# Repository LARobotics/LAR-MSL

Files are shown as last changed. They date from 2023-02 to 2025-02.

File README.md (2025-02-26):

LAR
# LAR@MSL

## Links
 - [Website] <https://lar.dei.uminho.pt/>
 - [Youtube] <https://www.youtube.com/@lar_uminho>
 - [Instagram] <https://www.instagram.com/lar_uminho>
 - [TikTok] <https://www.tiktok.com/@lar_uminho>
 - [Facebook] <https://www.facebook.com/profile.php?id=100088692420376>

## Our robot: 
Robot

# Base Station and Strategy:
The Base Station and Strategy was developed in Python 3.11 and is one of the most important tools for the robots to be able to play. It handles the communications between the Base Station and the robots and even from the RefBox using WebSockets. The Strategy works with the inputs from the robots, calculates the group of skills for that game state, and gives that information back to the robots.

# Calibration Tools:
This folder contains Calibration tools to simplify the calibration of cameras and their alignment. It was made in Python and saves a lot of time when the robot is disassembled and needs to be calibrated.

# Hardware and 3D CADS
Here are available the 3D CAD files from the robot, which is made by either aluminium or plastic PLA. There are still hardware being developed and some of them are from previous team generations, but the ones made this year are available here.

# Player
This is the main robot code that runs on the robot's main computer. It also has the ESP32 code that runs on the Robot Microcontroller.

# Tutorial
Here are some tutorials for the things that are used by the team, for example the use of YOLO, Cameras through Ethernet, Ubuntu installation etc…

# Yolo
In this folder are available Datasets and Code that are used by the Team. It is also being made a version of running the Yolo network in Golang, the language used in the Robot.

### Contacts
 - <fernando@dei.uminho.pt>
 - <gil@dei.uminho.pt>

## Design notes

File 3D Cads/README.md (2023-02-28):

LAR
# Hardware and 3D Cads

## Includes:
- Structure
- Dribbler
- Kick
- PCB
- Power Box
- Kinect Support
- Omni Support
- Lidar Support

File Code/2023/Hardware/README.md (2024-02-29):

# Hardware
Baudrate 115200

Timeout 200ms

##Installation

$ sudo chmod 777 /dev/ttyUSB*

$ go run . ttyUSB*

#Full packet (receive) :

String : bearing_angle,Battery,temperature_OMNI, X_displacement, Y_displacement

| Variable | Range |
| --- | --- |
| bearing_angle  | -180 -> 180  |
| Battery  | 0 -> max battery voltage  |
| temperature_OMNI  |  |
| X_displacement  | 0 -> 1000  |
| Y_displacement  | 0 -> 1000  |

#Commands

Full packet  (send)

String : linear_speed,angular_speed,direction,drib1_vel,drib2_vel, Kick_time #resetenc

| Variable | Range |
| --- | --- |
| linear_speed  | 0 -> 100  |
| angular_speed  | -100 -> 100  |
| direction  | 0 ->360  |
| drib1_vel  | 0 -> 100  |
| drib2_vel  | 0 -> 100  |
| Kick_time  | 0 -> 15 |

OMNI 3MD PID Components 

String: 'P',Kp, ki, kd 

| Variable | Range |
| --- | --- |
| Kp  | 0 -> 100  |
| Ki  | 0 -> 100  |
| Kd  | 0 ->360  |

OMNI 3MD angular speed 

String: 'W',rotational_sp 

| Variable | Range |
| --- | --- |
| angular_speed  | -100 -> 100  |

OMNI 3MD linear and rotational speed 
String: 'M',linear_speed,angular_speed,direction, 

| Variable | Range |
| --- | --- |
| linear_speed  | 0 -> 100  |
| angular_speed  | -100 -> 100  |
| direction  | 0 ->360  |

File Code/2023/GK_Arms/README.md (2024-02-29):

# GK_Arms
This repository is dedicated for the goal keeper moving parts.

For the moving parts to move, it is used a raspberry pi pico to control the motor (main.py).

The import.py is the file that sends via serial the command for the pi pico to activate the motor.

This repository contains a tutorial of how to install and use Thonny (IDE for raspberry pi pico)

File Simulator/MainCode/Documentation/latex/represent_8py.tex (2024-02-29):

\hypertarget{represent_8py}{}\doxysection{v03/represent.py File Reference}
\label{represent_8py}\index{v03/represent.py@{v03/represent.py}}
\doxysubsection*{Classes}
\begin{DoxyCompactItemize}
\item 
class \mbox{\hyperlink{classrepresent_1_1_draw}{represent.\+Draw}}
\end{DoxyCompactItemize}
\doxysubsection*{Namespaces}
\begin{DoxyCompactItemize}
\item 
namespace \mbox{\hyperlink{namespacerepresent}{represent}}
\end{DoxyCompactItemize}
\doxysubsection*{Functions}
\begin{DoxyCompactItemize}
\item 
def \mbox{\hyperlink{namespacerepresent_aa5588bfe59ad341def799e75c61164e5}{represent.\+pol2cart}} (rho, phi)
\end{DoxyCompactItemize}
\doxysubsection*{Variables}
\begin{DoxyCompactItemize}
\item 
tuple \mbox{\hyperlink{namespacerepresent_a306ae13e5d31331a7cd58b41778ff506}{represent.\+server\+Address\+Port}} = (\char`\"{}localhost\char`\"{}, 20000)
\item 
\mbox{\hyperlink{namespacerepresent_a5a9aeb93b6b3772014caec14be52f55a}{represent.\+UDPClient\+Socket}} = socket.\+socket(family=socket.\+AF\+\_\+\+INET, type=socket.\+SOCK\+\_\+\+DGRAM)
\item 
list \mbox{\hyperlink{namespacerepresent_a486d0cff411ffd8d014e9d40a42c79ba}{represent.\+Ball}} = \mbox{[}0, 0\mbox{]}
\item 
list \mbox{\hyperlink{namespacerepresent_a32969535d1ac8ca3c024cc3d4650f2a2}{represent.\+Robots}} = \mbox{[}\mbox{[}0, 0, 0\mbox{]}, \mbox{[}0, 0, 0\mbox{]}, \mbox{[}0, 0, 0\mbox{]}, \mbox{[}0, 0, 0\mbox{]}, \mbox{[}0, 0, 0\mbox{]}\mbox{]}
\item 
\mbox{\hyperlink{namespacerepresent_aa6ba4148b26b317da122f96b56750bab}{represent.\+App}} = Draw(3)
\item 
\mbox{\hyperlink{namespacerepresent_a6c4a21d543502a43690d8051032f9db6}{represent.\+message}} = UDPClient\+Socket.\+recvfrom(1024)
\item 
\mbox{\hyperlink{namespacerepresent_ad7f4d1bb368262bdb7cb67b091ef459e}{represent.\+To\+Draw}} = eval(message\mbox{[}0\mbox{]}.decode())
\item 
\mbox{\hyperlink{namespacerepresent_a0a21a2b54add9912bfbd176ac16a054a}{represent.\+tempo}} = time.\+time()
\end{DoxyCompactItemize}

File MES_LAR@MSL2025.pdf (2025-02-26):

# LAR@MSL – M.E.S. 2025

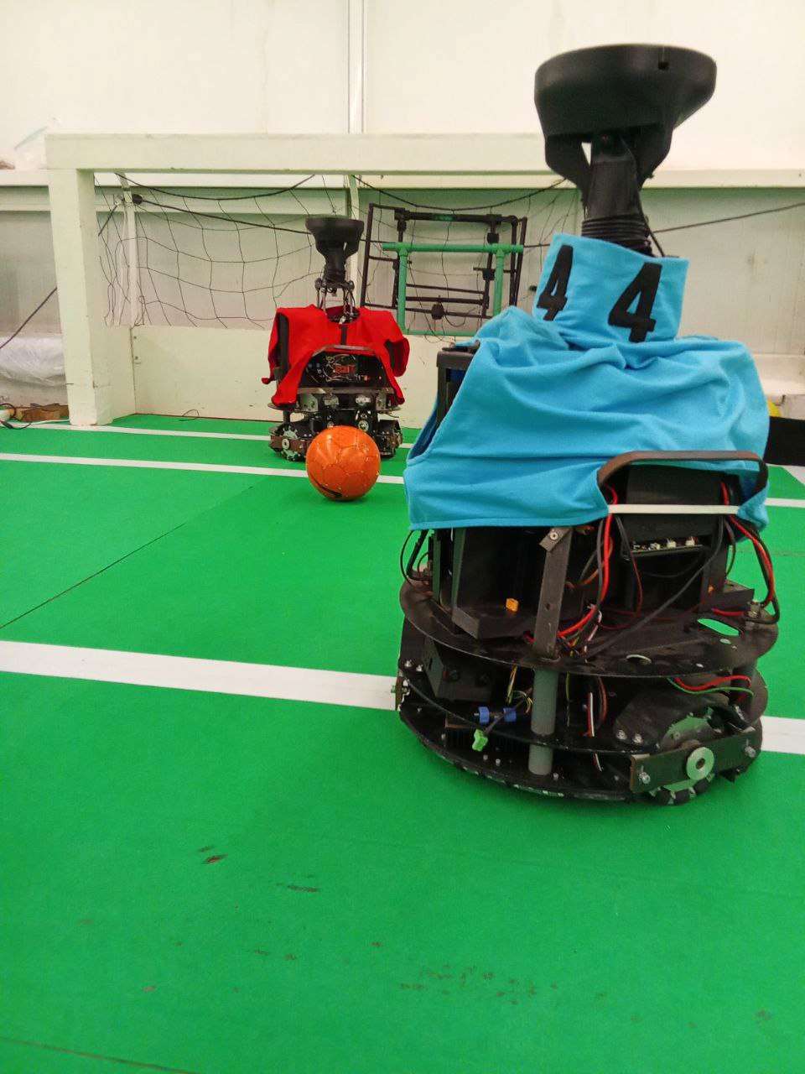
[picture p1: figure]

## Robot Overview

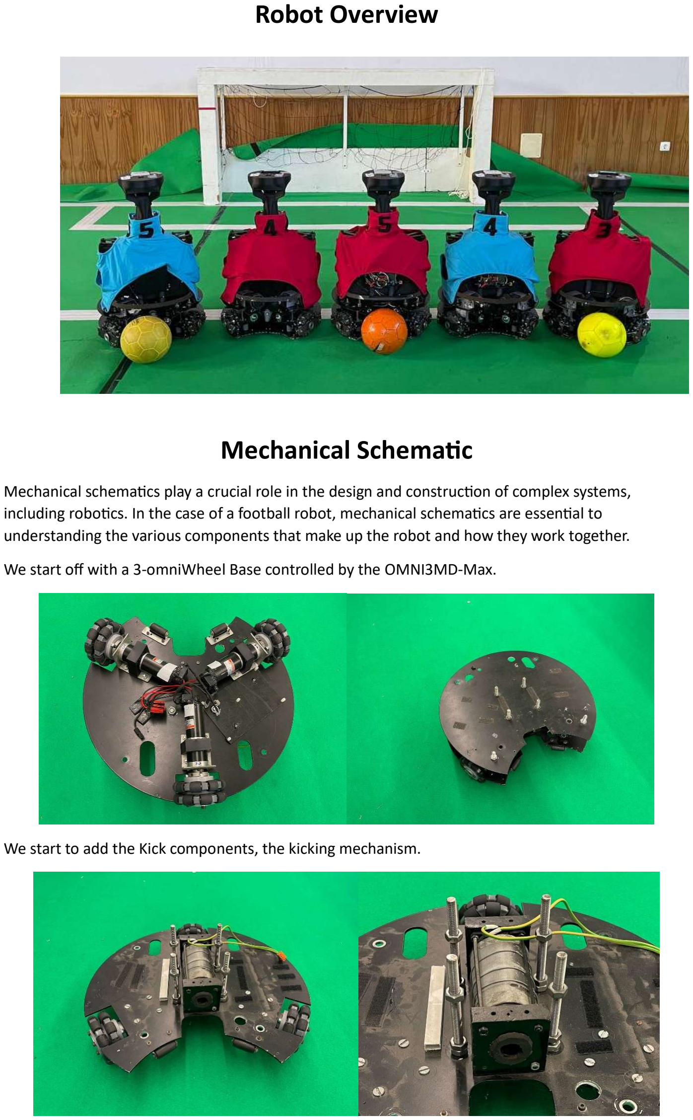
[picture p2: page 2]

## Mechanical Schemac

Mechanical schemacs play a crucial role in the design and construcon of complex systems, including robocs. In the case of a football robot, mechanical schemacs are essenal to understanding the various components that make up the robot and how they work together. We start off with a 3-omniWheel Base controlled by the OMNI3MD-Max.

We start to add the Kick components, the kicking mechanism.

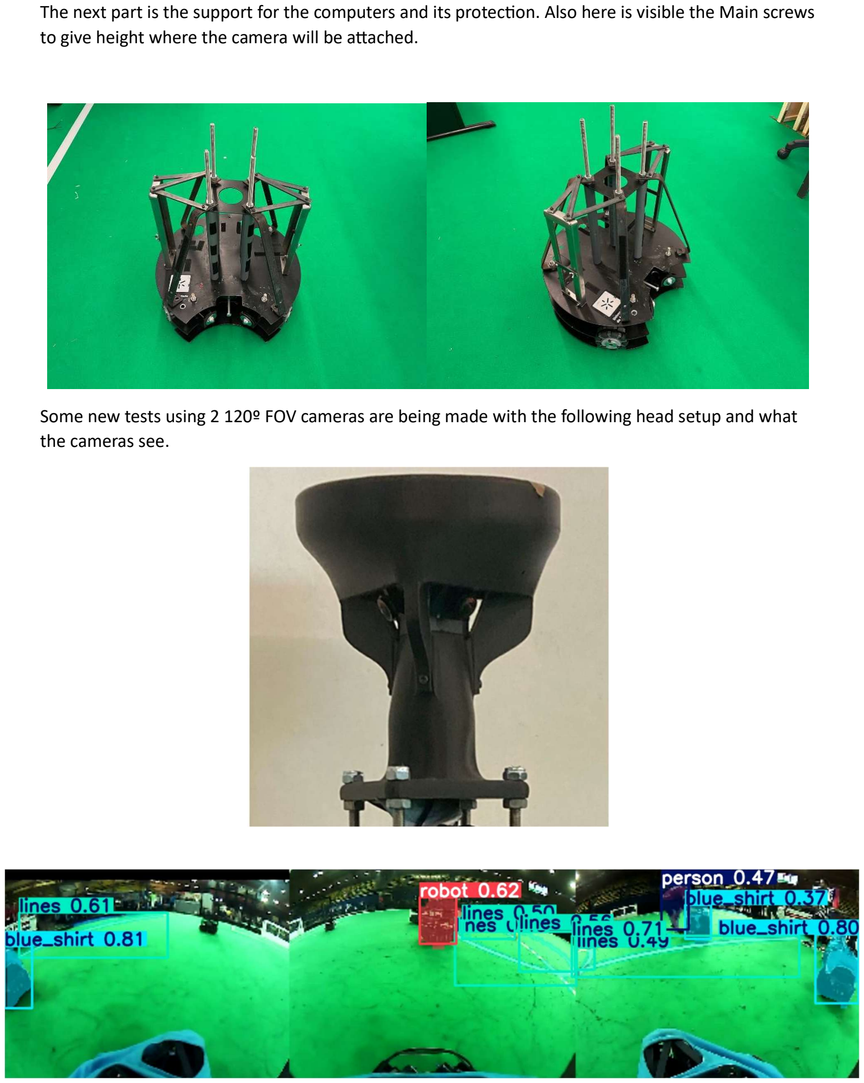
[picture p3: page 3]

The next part is the support for the computers and its protecon. Also here is visible the Main screws to give height where the camera will be aached.

Some new tests using 2 120º FOV cameras are being made with the following head setup and what the cameras see.

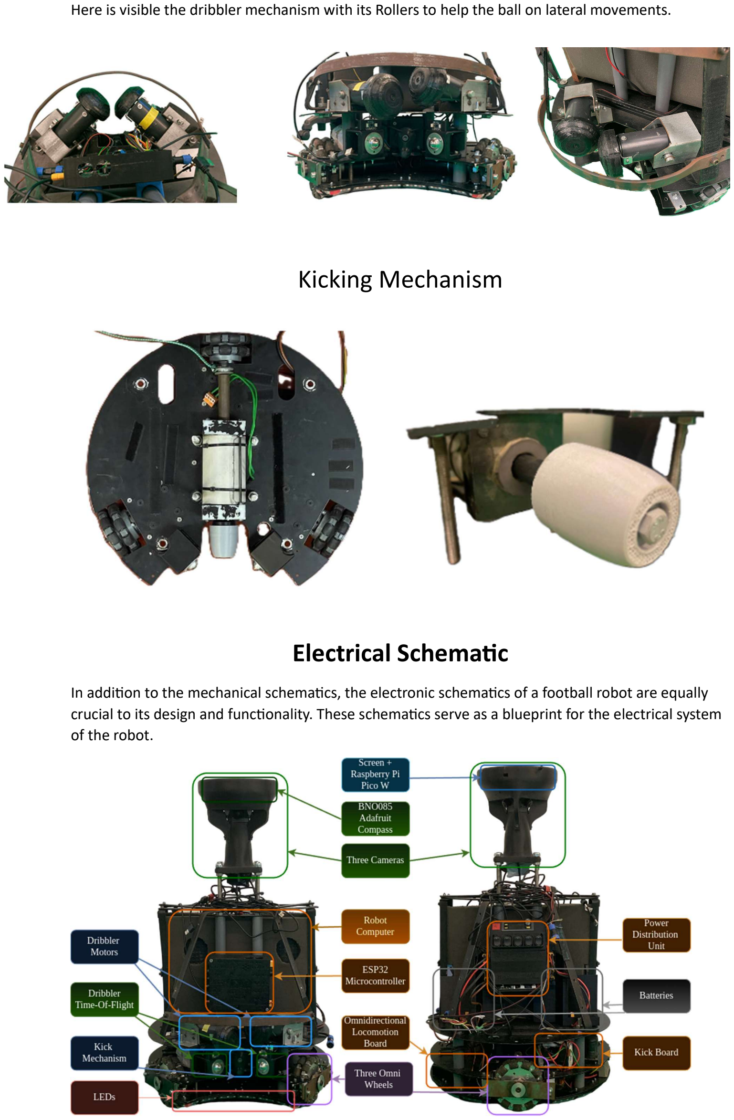
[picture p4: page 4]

Here is visible the dribbler mechanism with its Rollers to help the ball on lateral movements.

## Kicking Mechanism

## Electrical Schemac

In addion to the mechanical schemacs, the electronic schemacs of a football robot are equally crucial to its design and funconality. These schemacs serve as a blueprint for the electrical system of the robot.

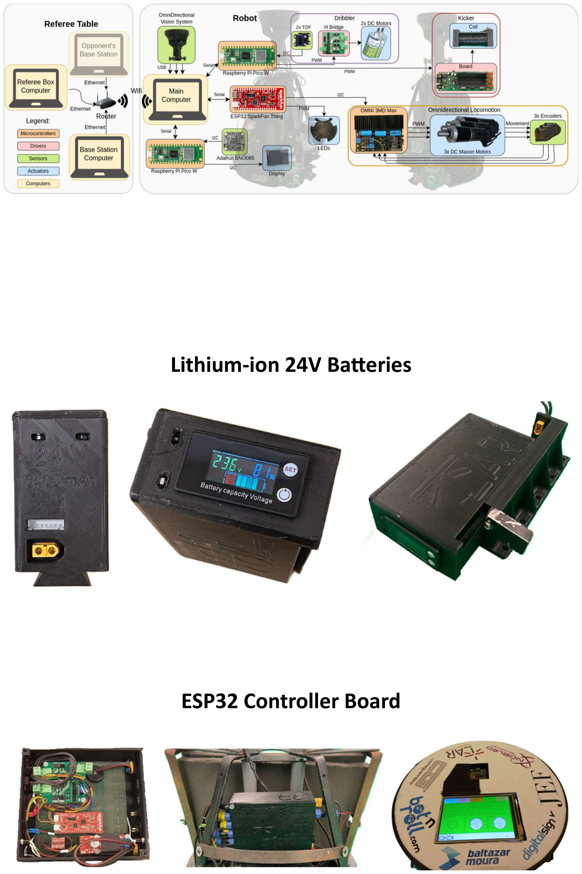
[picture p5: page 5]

## Lithium-ion 24V Baeries

## ESP32 Controller Board

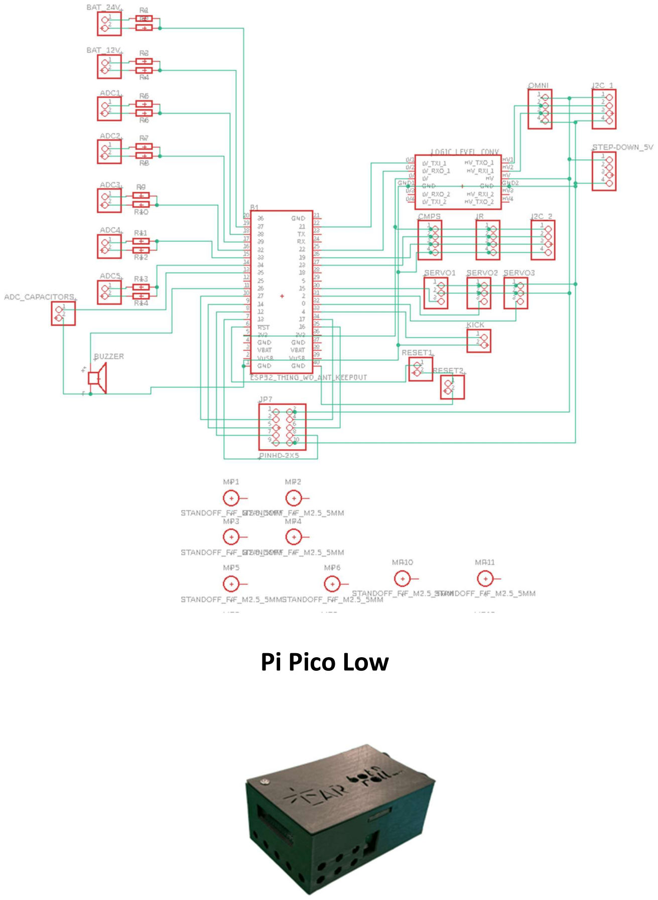
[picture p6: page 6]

## Pi Pico Low

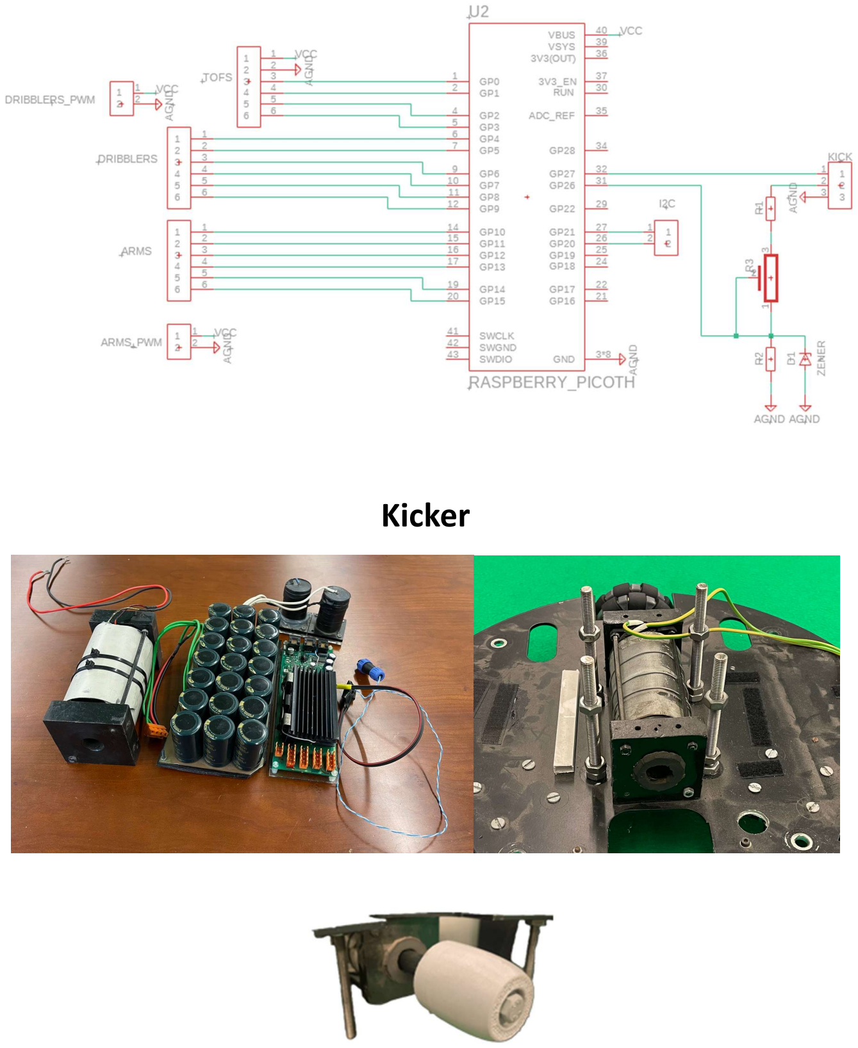
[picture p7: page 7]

## Kicker

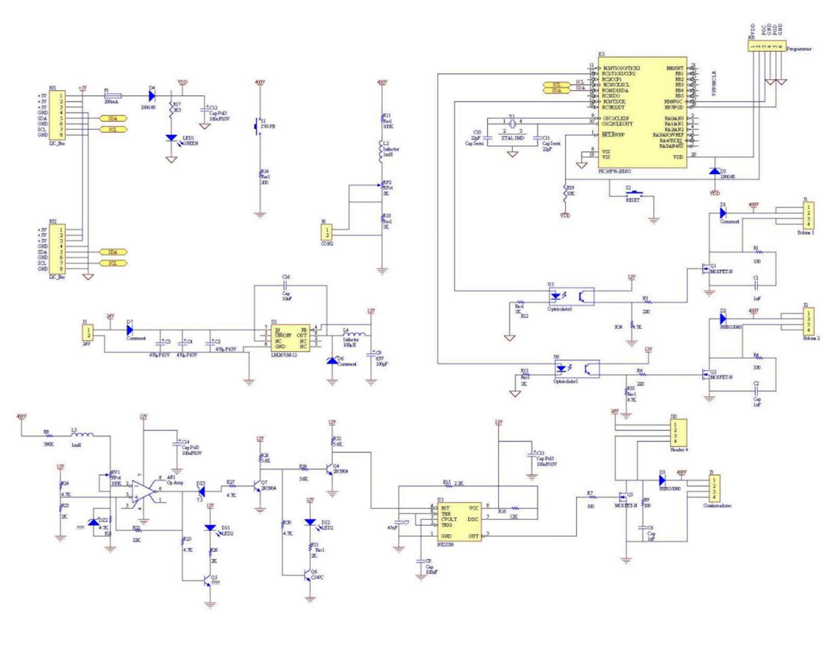
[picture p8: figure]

## Power Box

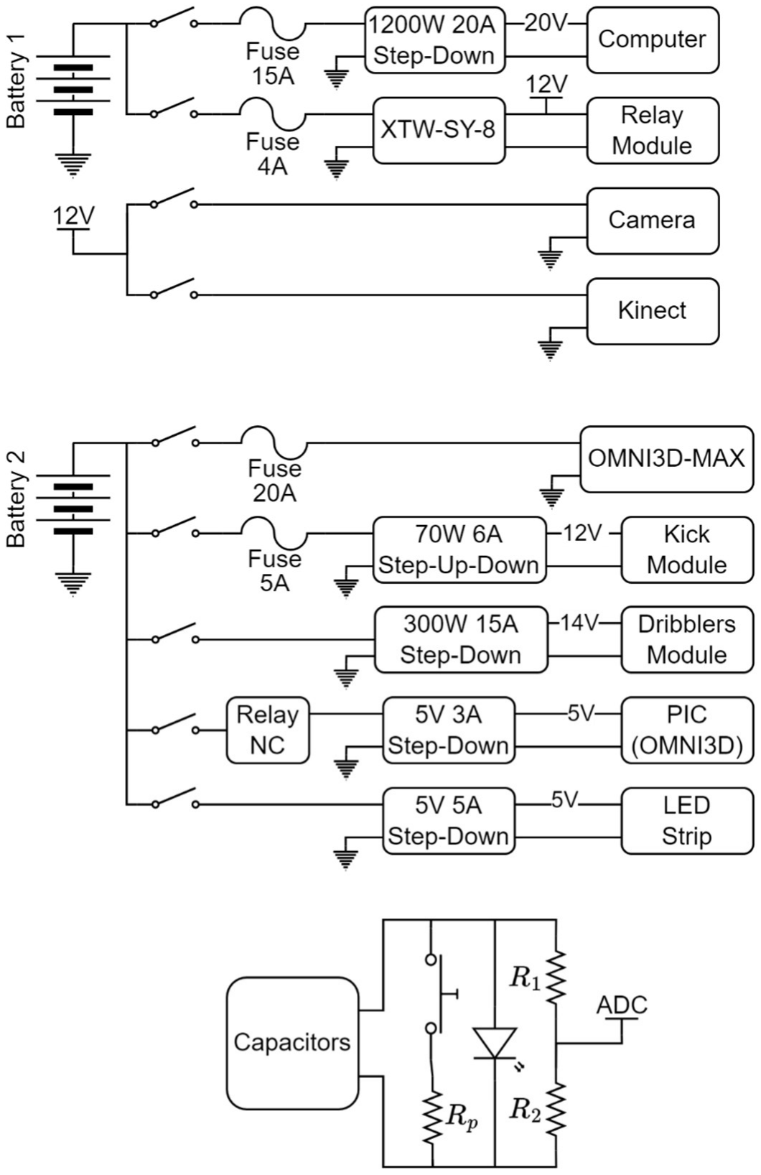
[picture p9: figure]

## Soware Schemac

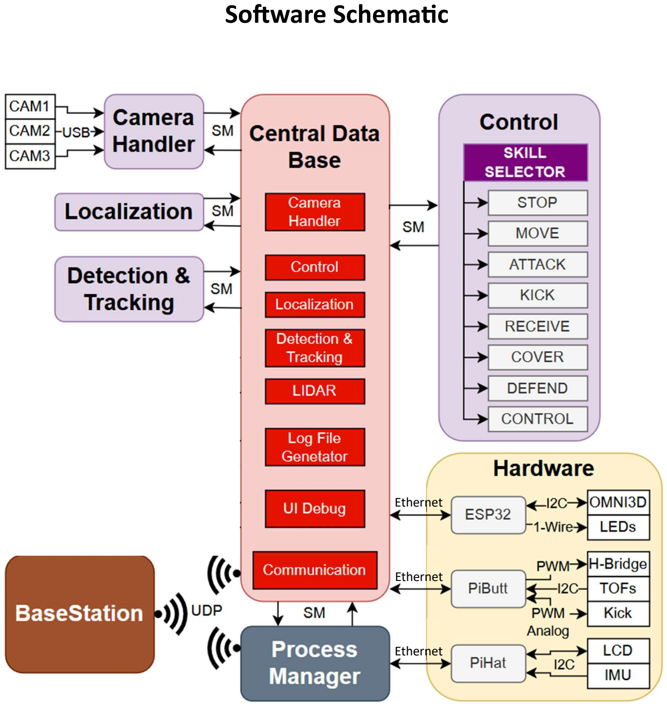
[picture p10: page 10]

Ethernet

Ethernet

Ethernet

## Base Staon UI

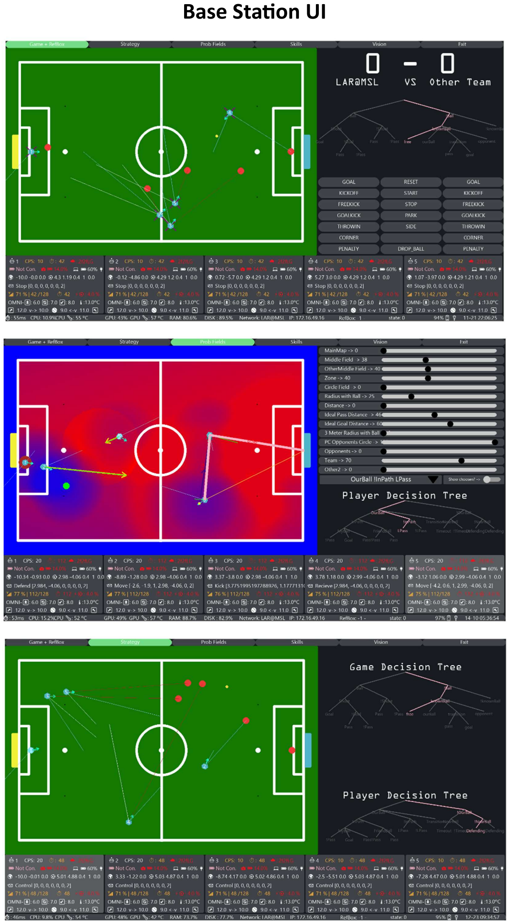
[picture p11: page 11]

## Simulator Architecture

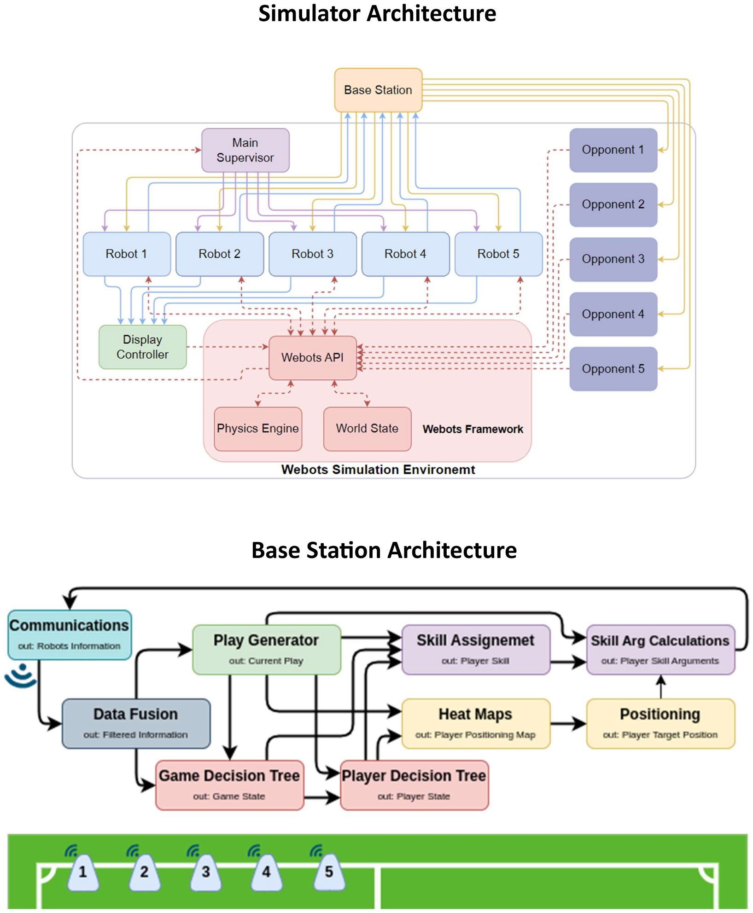
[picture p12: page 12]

## Base Staon Architecture

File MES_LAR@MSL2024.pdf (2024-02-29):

# LAR@MSL – M.E.S. 2024

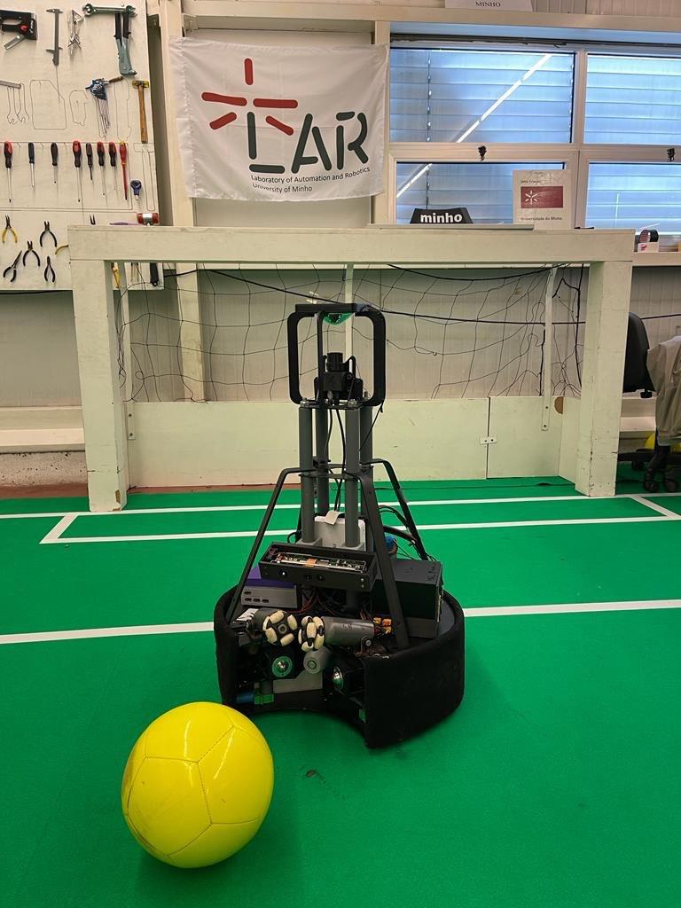
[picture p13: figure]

## Robot Overview

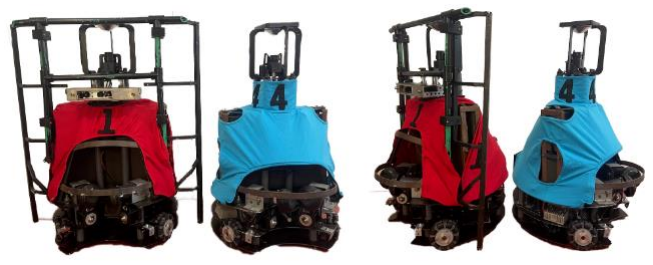
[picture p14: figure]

## Mechanical Schematic

Mechanical schematics play a crucial role in the design and construction of complex systems, including robotics. In the case of a football robot, mechanical schematics are essential to understanding the various components that make up the robot and how they work together.

We start off with a 3-omniWheel Base controlled by the OMNI3MD-Max.

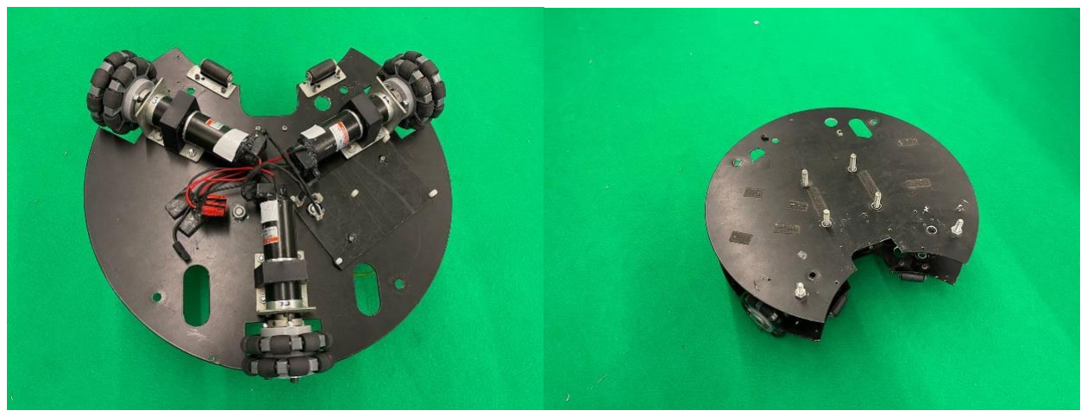
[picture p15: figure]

We start to add the Kick components, the kicking mechanism.

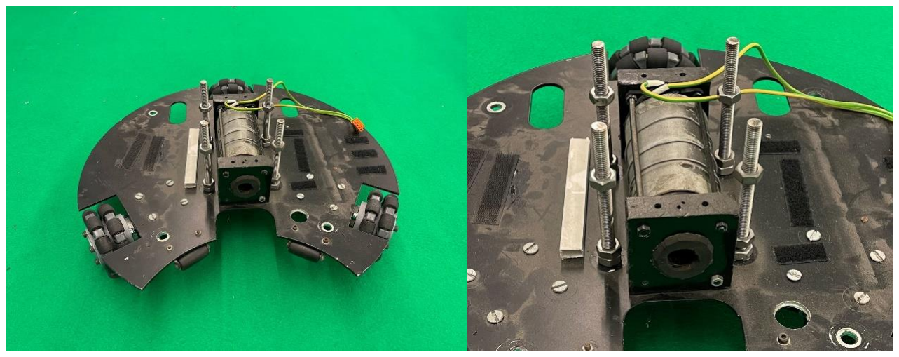
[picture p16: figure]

The next part is the support for the computers and its protection. Also here is visible the Main screws to give height where the camera will be attached.

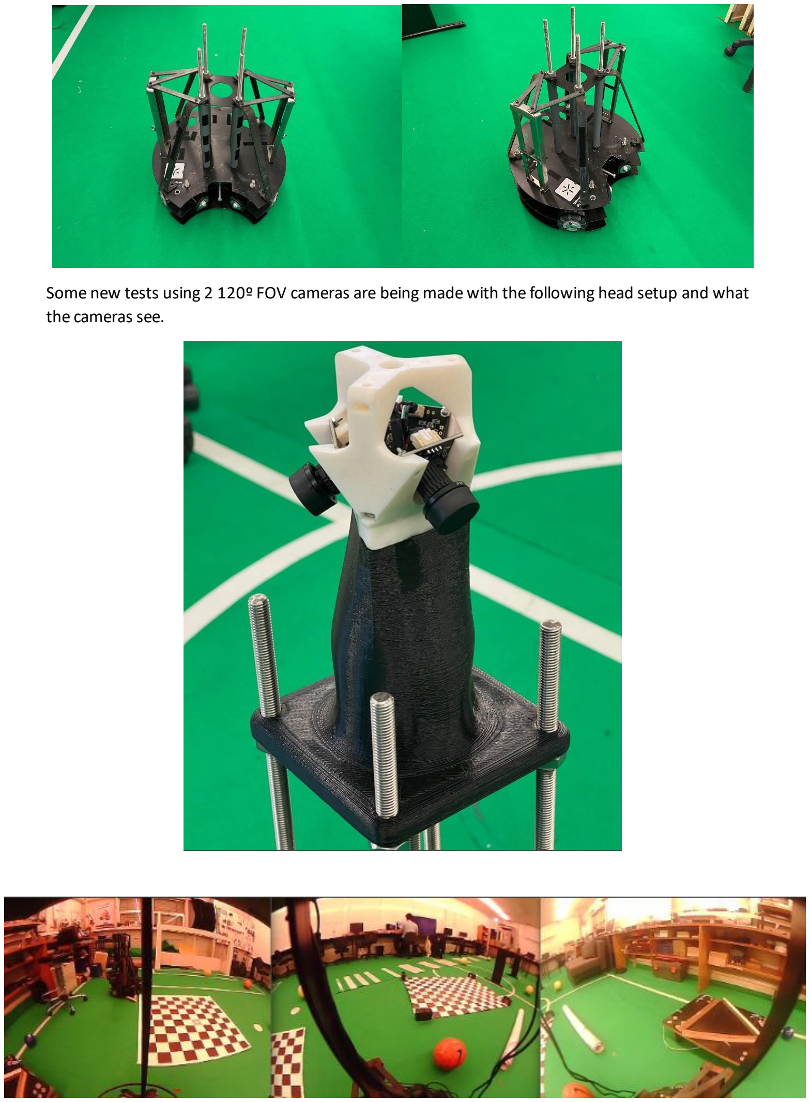
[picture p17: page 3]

Some new tests using 2 120º FOV cameras are being made with the following head setup and what the cameras see.

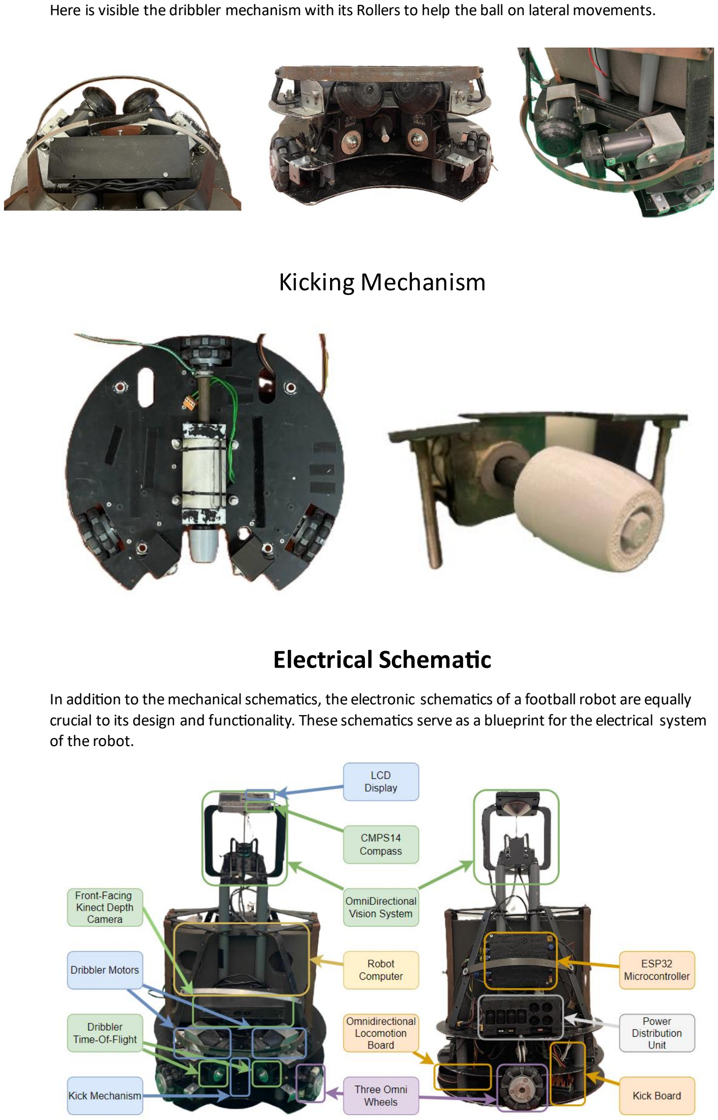
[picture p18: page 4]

Here is visible the dribbler mechanism with its Rollers to help the ball on lateral movements.

## Kicking Mechanism

## Electrical Schematic

In addition to the mechanical schematics, the electronic schematics of a football robot are equally crucial to its design and functionality. These schematics serve as a blueprint for the electrical system of the robot.

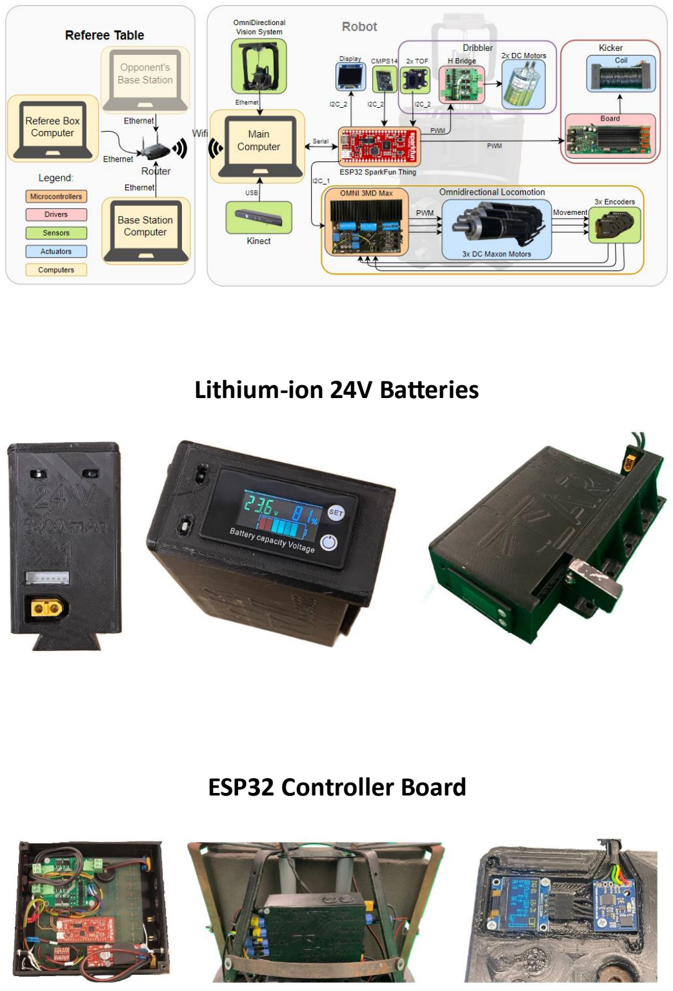
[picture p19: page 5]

## Lithium-ion 24V Batteries

## ESP32 Controller Board

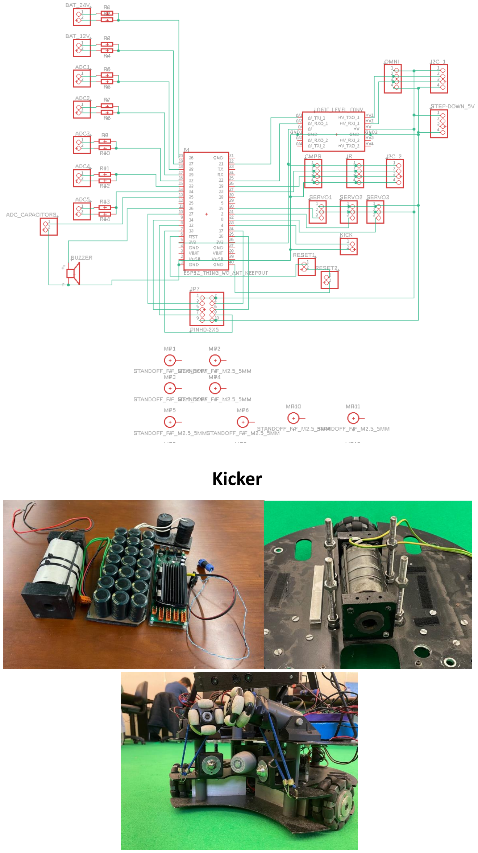
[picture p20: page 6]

## Kicker

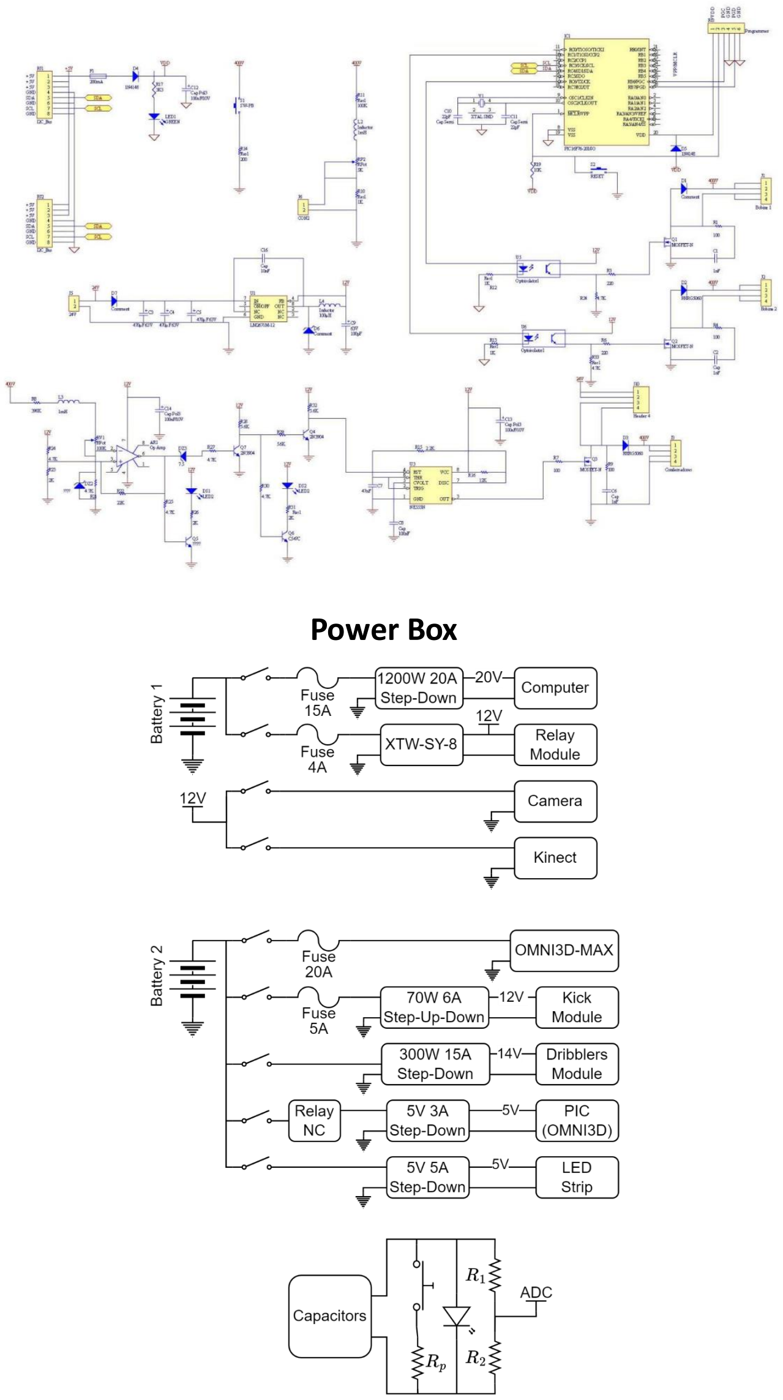
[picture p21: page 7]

## Power Box

## Software Schematic

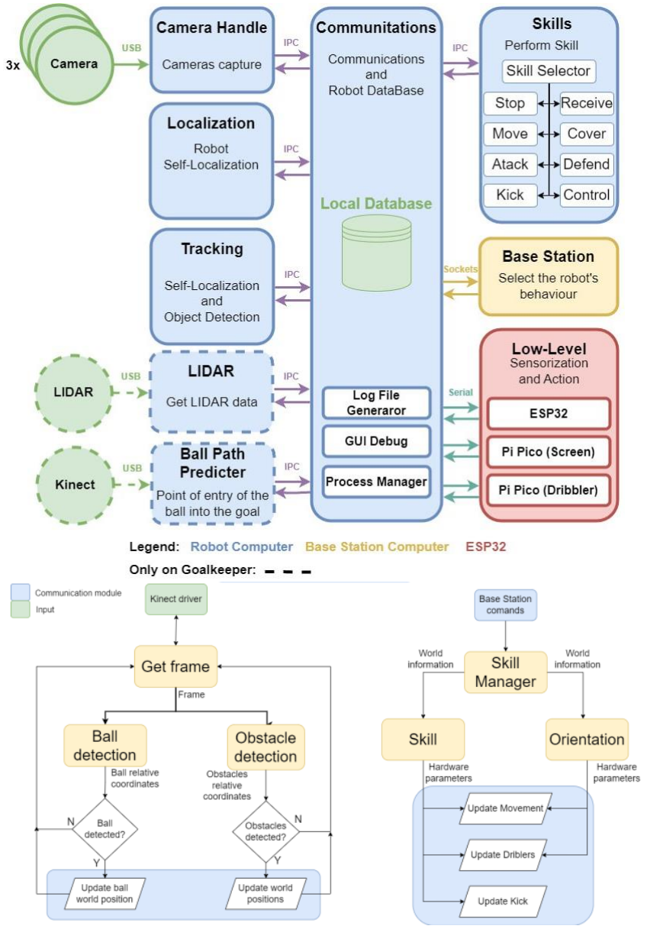
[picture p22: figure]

## Base Station UI

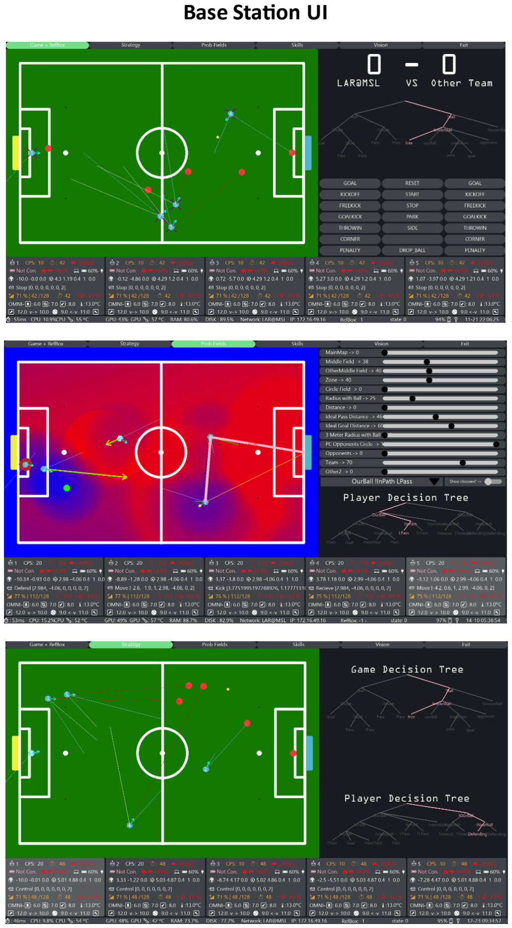
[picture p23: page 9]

## Simulator Architecture

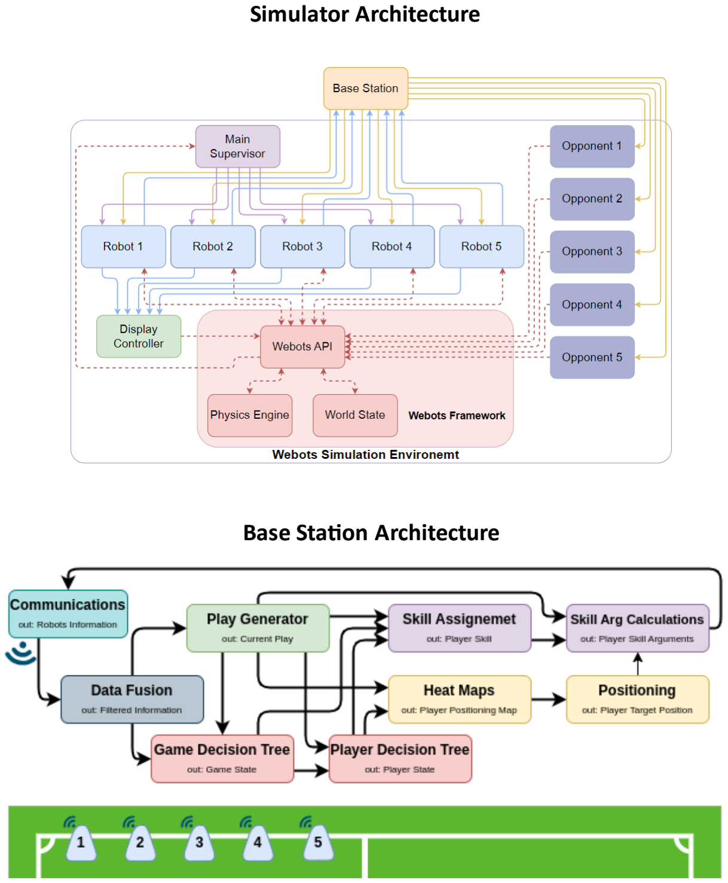
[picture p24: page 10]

## Base Station Architecture

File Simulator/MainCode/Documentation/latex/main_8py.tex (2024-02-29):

\hypertarget{main_8py}{}\doxysection{v03/main.py File Reference}
\label{main_8py}\index{v03/main.py@{v03/main.py}}
\doxysubsection*{Namespaces}
\begin{DoxyCompactItemize}
\item 
namespace \mbox{\hyperlink{namespacemain}{main}}
\end{DoxyCompactItemize}
\doxysubsection*{Variables}
\begin{DoxyCompactItemize}
\item 
\mbox{\hyperlink{namespacemain_a2c732fd126c78a0f5d3bbc0ba2087bfc}{main.\+Strategy\+DT}} = json.\+load(f)
\item 
int \mbox{\hyperlink{namespacemain_a760b0c315261c045a6205f78237a3ac3}{main.\+DRAW}} = 0
\item 
\mbox{\hyperlink{namespacemain_a4a80d210025e65a48c2237a3ff27bcb3}{main.\+App}} = Draw(3)
\item 
tuple \mbox{\hyperlink{namespacemain_a59063a6237aa4927da56261ae75edbe5}{main.\+server\+Address\+Port}} = (\char`\"{}localhost\char`\"{}, 19998)
\item 
\mbox{\hyperlink{namespacemain_a476fcb878fb3965b1c55fa5c442c6c20}{main.\+Processing\+Socket}} = socket.\+socket(family=socket.\+AF\+\_\+\+INET, type=socket.\+SOCK\+\_\+\+DGRAM)
\item 
list \mbox{\hyperlink{namespacemain_a289e4044e5b783704fccca758f093d85}{main.\+IPS}} = \mbox{[}\char`\"{}localhost\char`\"{}, \char`\"{}localhost\char`\"{}, \char`\"{}localhost\char`\"{}, \char`\"{}localhost\char`\"{}, \char`\"{}localhost\char`\"{}, \char`\"{}localhost\char`\"{}, 2\mbox{]}
\item 
list \mbox{\hyperlink{namespacemain_a74abab1c427332984c688174a7a2fa0d}{main.\+Robots}} = \mbox{[}Robot(a+1, IPS\mbox{[}0\mbox{]}, IPS\mbox{[}a+1\mbox{]}, 0, IPS\mbox{[}-\/1\mbox{]}) for a in range(5)\mbox{]}
\item 
int \mbox{\hyperlink{namespacemain_ae35795b6540bc96398be5e8232eb3c04}{main.\+kick}} = 0
\item 
int \mbox{\hyperlink{namespacemain_ad7991273b99bb2dfcba025791cece825}{main.\+recebe}} = 0
\item 
\mbox{\hyperlink{namespacemain_a1eb846a19d2fb4a2dd52b06531da303d}{main.\+init\+Time}} = time.\+time()
\item 
\mbox{\hyperlink{namespacemain_a79977f30964906ba8f47e199d7142cc0}{main.\+loop\+Time}} = time.\+time()
\item 
\mbox{\hyperlink{namespacemain_ada24c0f5d143f130aceaf05ae35895fd}{main.\+end}}
\item 
\mbox{\hyperlink{namespacemain_a2919b89f5fa43212425c4171bc4e460f}{main.\+packet}}
\end{DoxyCompactItemize}

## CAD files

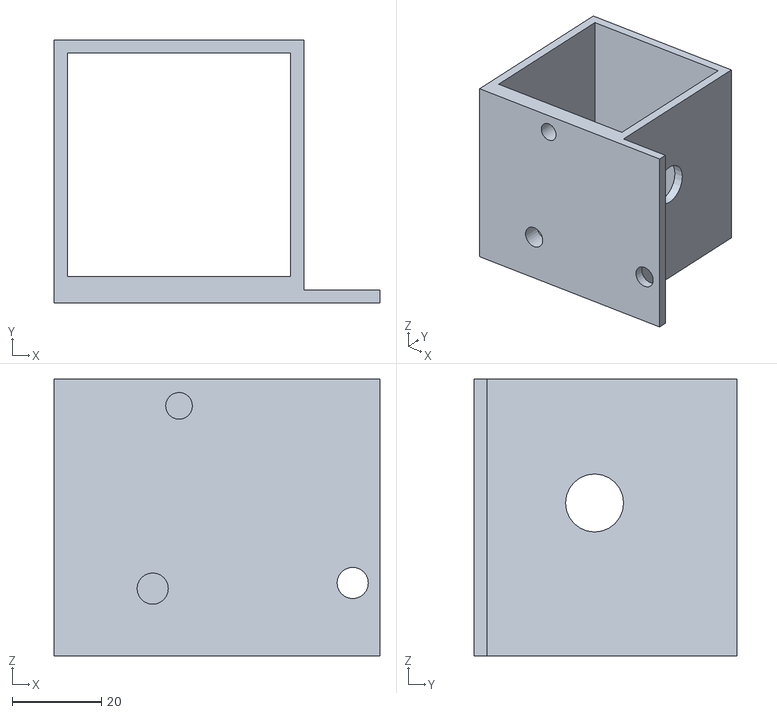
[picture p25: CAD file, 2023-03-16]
3D Cads/Dribbler/Dribbler_4E (cube).obj
73.0 x 59.0 x 62.0

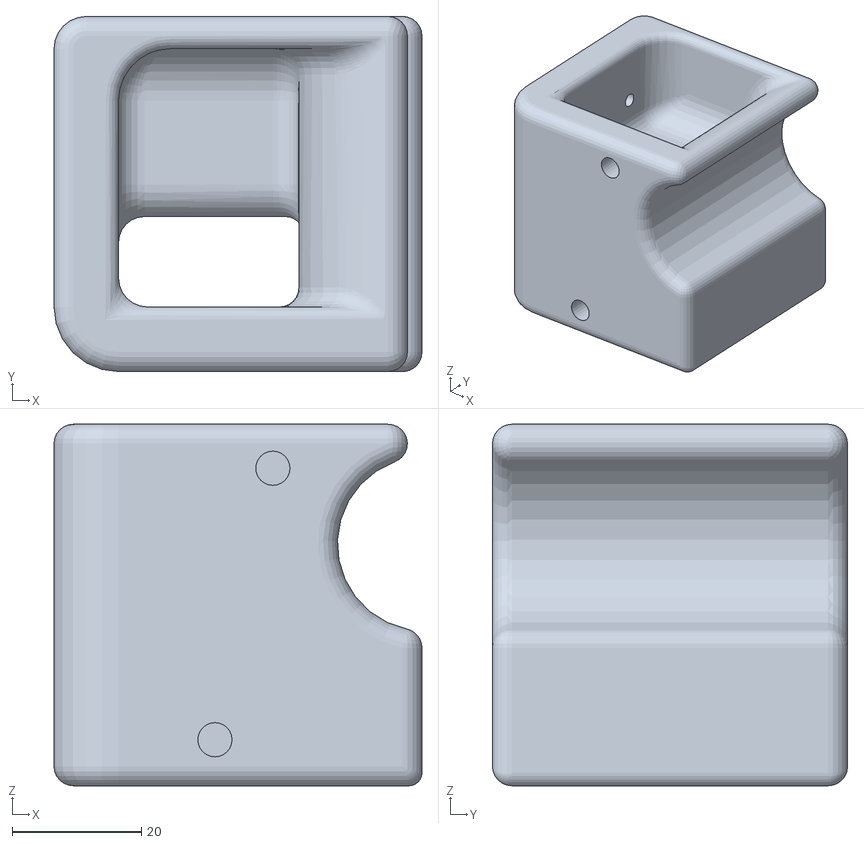
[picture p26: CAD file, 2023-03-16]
3D Cads/Dribbler/Rollers/LeftRollerCube.obj
57.0 x 55.0 x 56.0

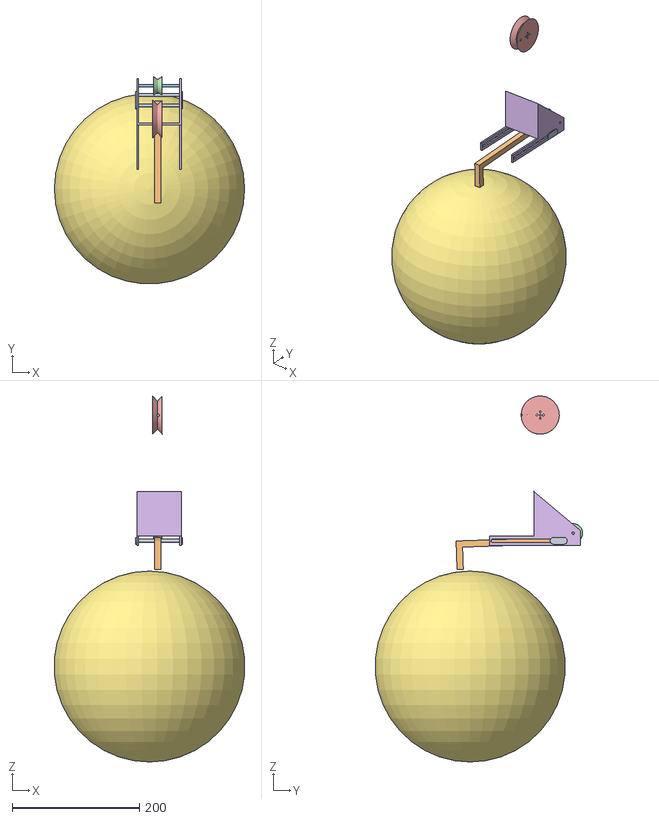
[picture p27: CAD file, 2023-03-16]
3D Cads/Kick/Kick.obj
299.0 x 325.6 x 575.0

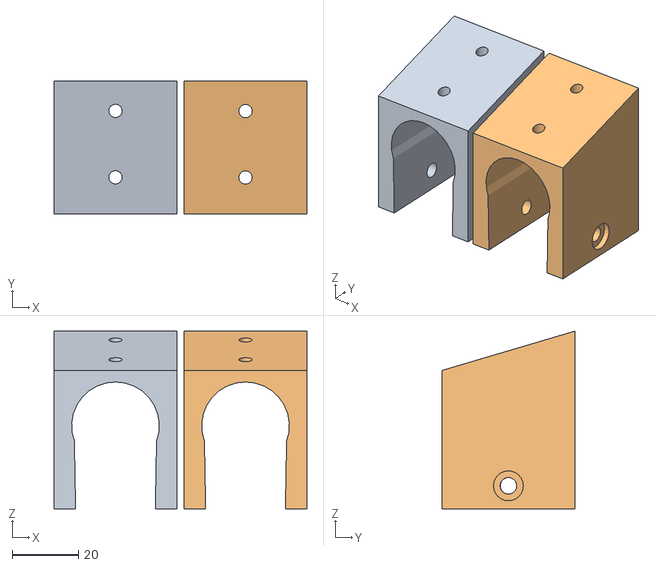
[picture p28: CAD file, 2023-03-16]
3D Cads/Kinect Support/BoxSupport.obj
76.1 x 40.1 x 53.5

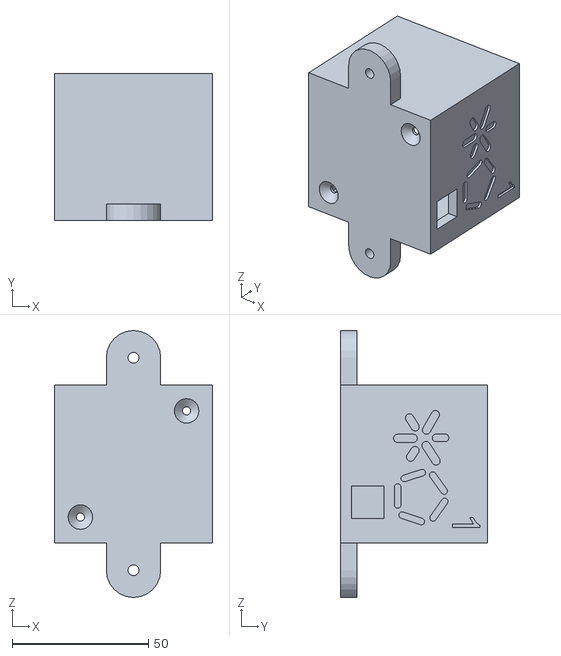
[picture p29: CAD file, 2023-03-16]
3D Cads/Lidar Support/LidarSupport.obj
58.0 x 54.0 x 98.0

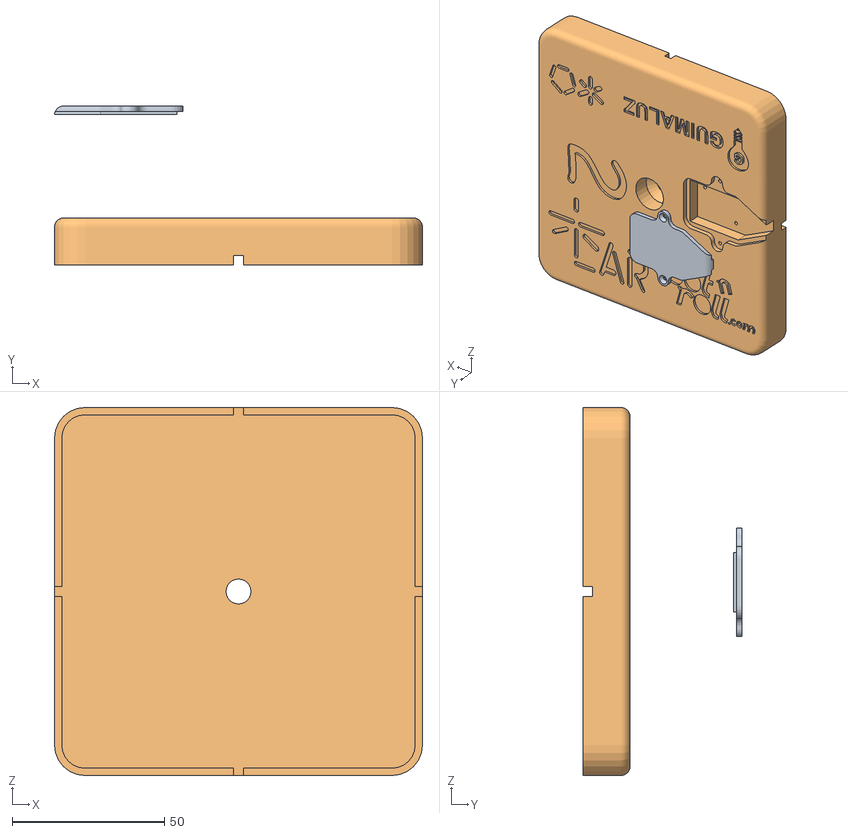
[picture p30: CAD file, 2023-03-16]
3D Cads/Omni Support/RobotCover.obj
121.0 x 52.3 x 121.0

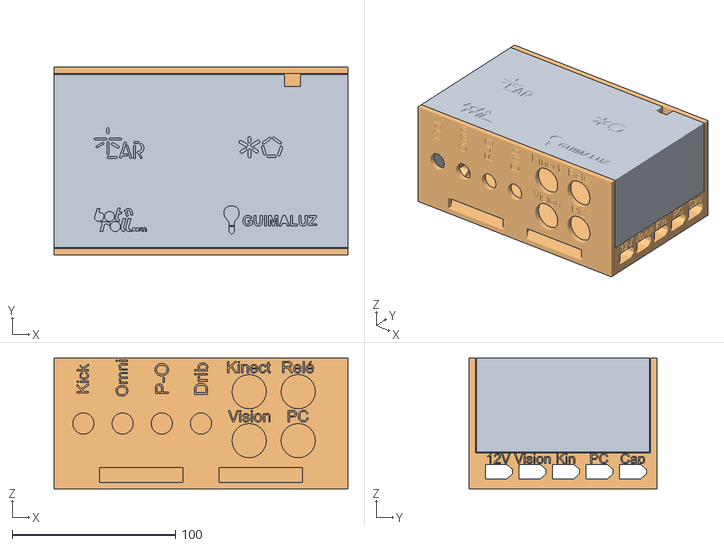
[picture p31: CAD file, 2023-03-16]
3D Cads/Power Box/PowerBox.obj
180.0 x 115.0 x 80.0

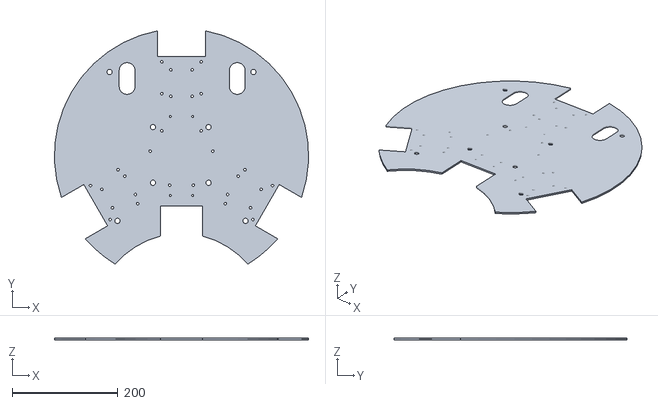
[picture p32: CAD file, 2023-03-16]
3D Cads/Structure/MiddlePlate.obj
479.4 x 440.6 x 3.00

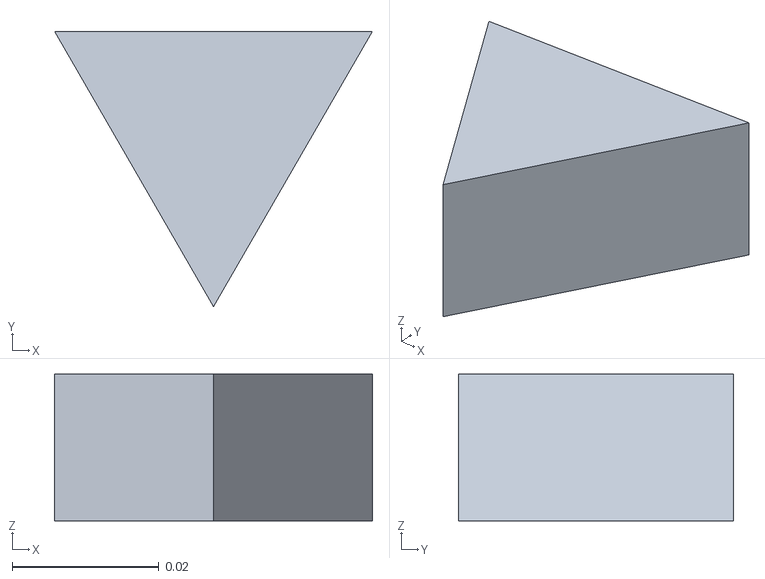
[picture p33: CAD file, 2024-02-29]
Simulator/otherSimulationFiles/MSLSuperSimplePyramide.stl
0.0433 x 0.0375 x 0.02

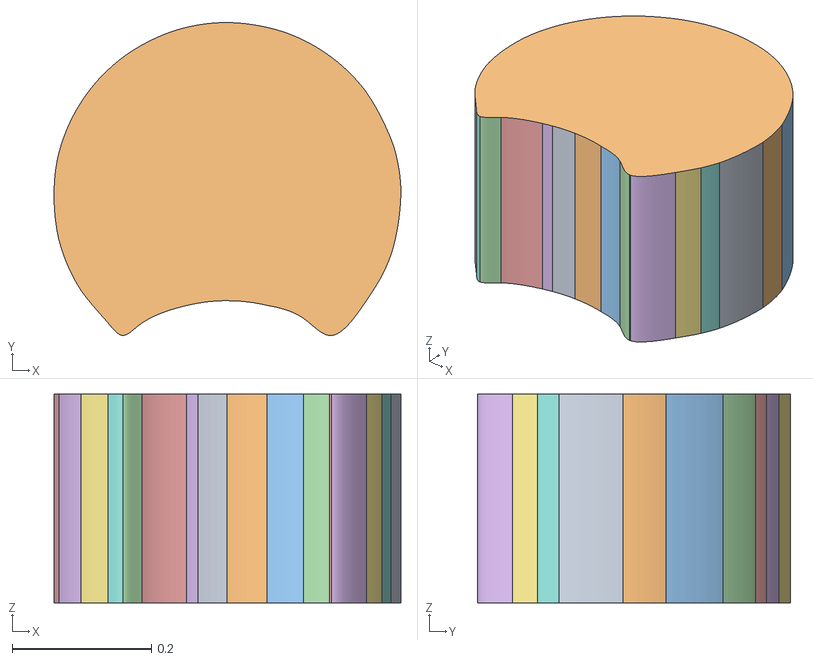
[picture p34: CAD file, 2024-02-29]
Simulator/SimuladorCoppelia/RobotV2.obj
0.499 x 0.45 x 0.3

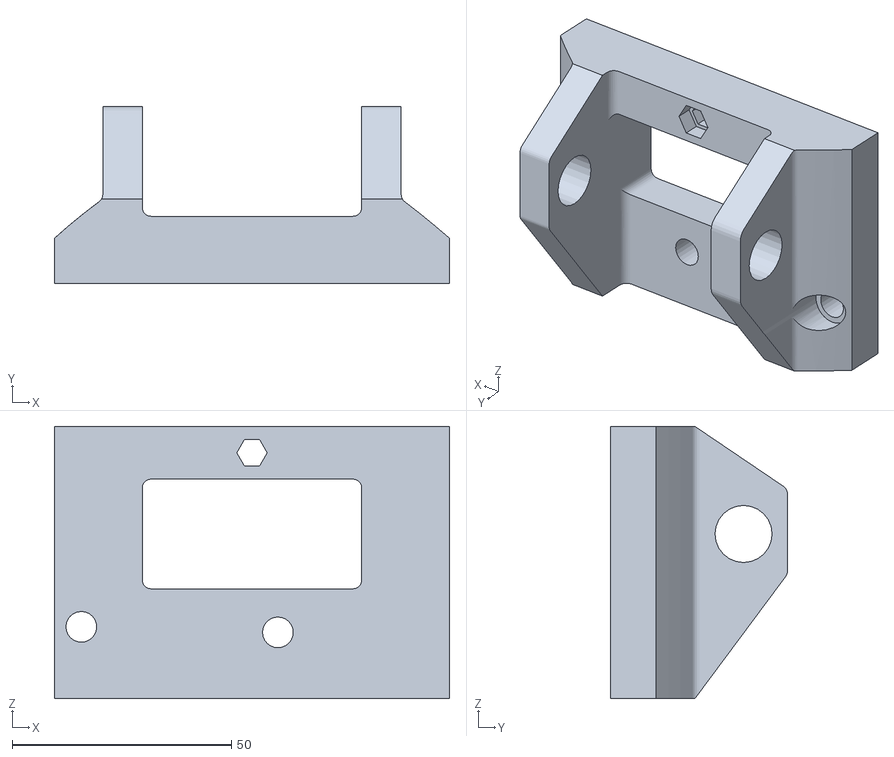
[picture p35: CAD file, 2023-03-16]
3D Cads/Dribbler/DribblerSupport_4E.obj
90.0 x 40.3 x 62.0

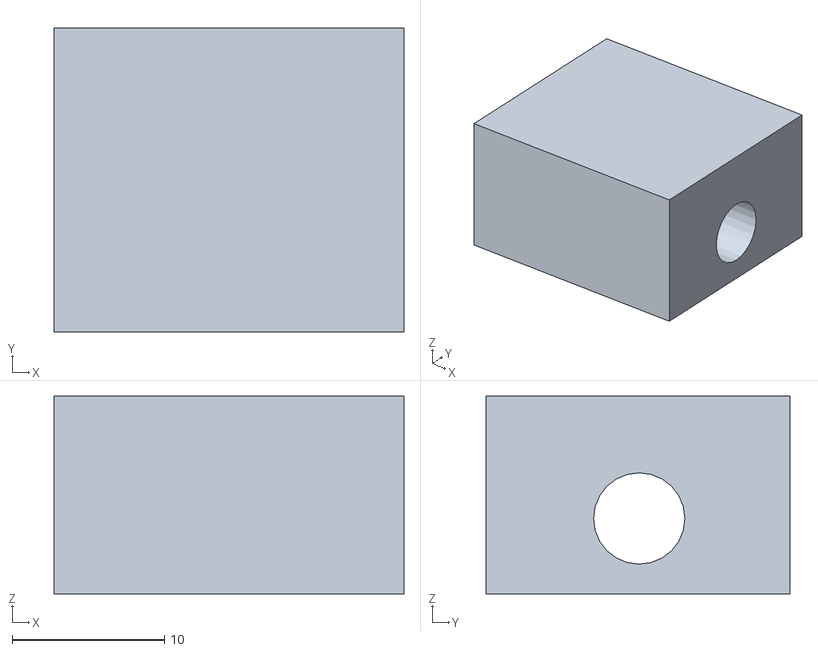
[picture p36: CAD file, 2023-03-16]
3D Cads/Kinect Support/BoxSupport2.obj
23.0 x 20.0 x 13.0

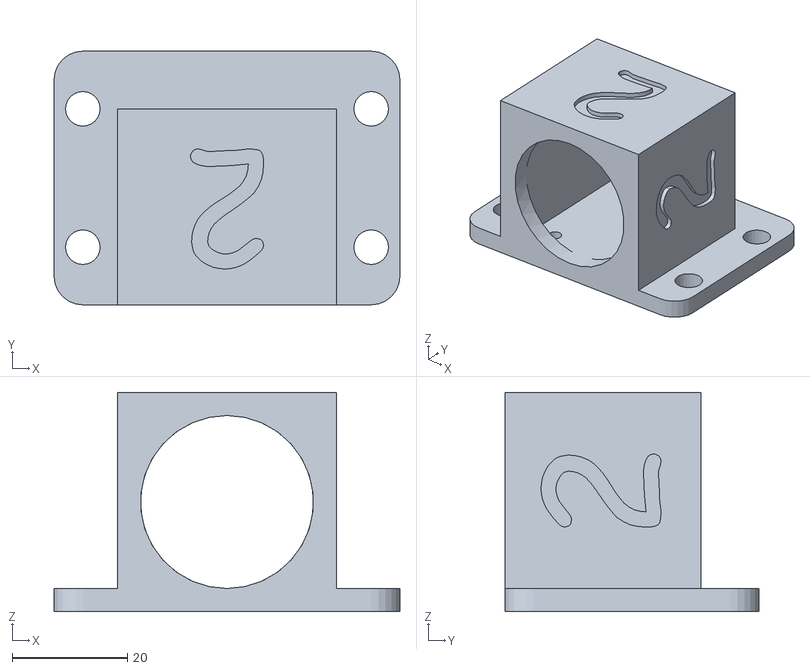
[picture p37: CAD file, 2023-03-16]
3D Cads/Omni Support/OmniSupport.obj
60.0 x 44.0 x 38.0

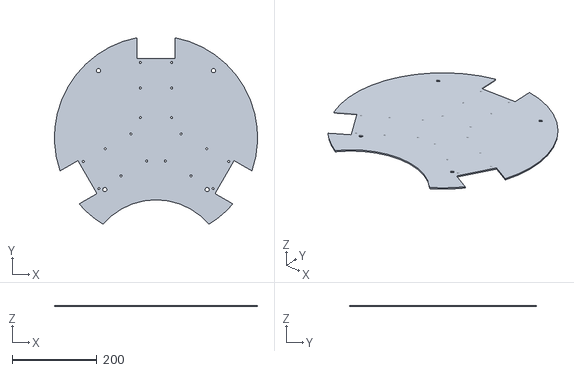
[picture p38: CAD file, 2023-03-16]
3D Cads/Structure/DownPlate.obj
479.4 x 440.6 x 3.00

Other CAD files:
3D Cads/Dribbler/Rollers/RightRollerCube.obj
Simulator/otherSimulationFiles/MSLSimulatorBody.stl
Simulator/SimuladorCoppelia/Robo.stl
3D Cads/ Cabeça/Baixo.f3z
3D Cads/ Cabeça/Base+Cima.f3d
3D Cads/ Cabeça/Cabeca.f3z
3D Cads/ Cabeça/Ecrã/EcraVoldePrint.f3z
3D Cads/ Cabeça/Ecrã/EcraVoldeprint.f3d
3D Cads/ Cabeça/Ecrã/EncaixeEcraPoncha.f3d
3D Cads/ Cabeça/Ecrã/Raspberry_Pi_2_Case_For_Creality_Ender_3_Pro_v054.f3d
3D Cads/ Cabeça/Ecrã/Suporte+Pi+Camera_Poncha.f3d
3D Cads/ Cabeça/Ecrã/SuporteCabecaAnet.f3z
3D Cads/ Cabeça/Ecrã/V4_CASE.f3d
3D Cads/ Cabeça/Ecrã/X_Belt_GT2__Gates_v3.f3d
3D Cads/ Cabeça/Ecrã/ecra+Pi+Pico (1).f3d
3D Cads/ Cabeça/Ecrã/ecra+Pi+Pico.f3d
3D Cads/ Cabeça/Ecrã/screen7_legs.f3d
3D Cads/ Cabeça/Ecrã/suporte_extruder_poncha.f3z
3D Cads/ Cabeça/Head+2024.f3z
3D Cads/ Cabeça/Suport+Topo+V2.f3z
3D Cads/ Cabeça/Suport+Topo.f3z
3D Cads/ Cabeça/SuporteBaixo.f3z
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

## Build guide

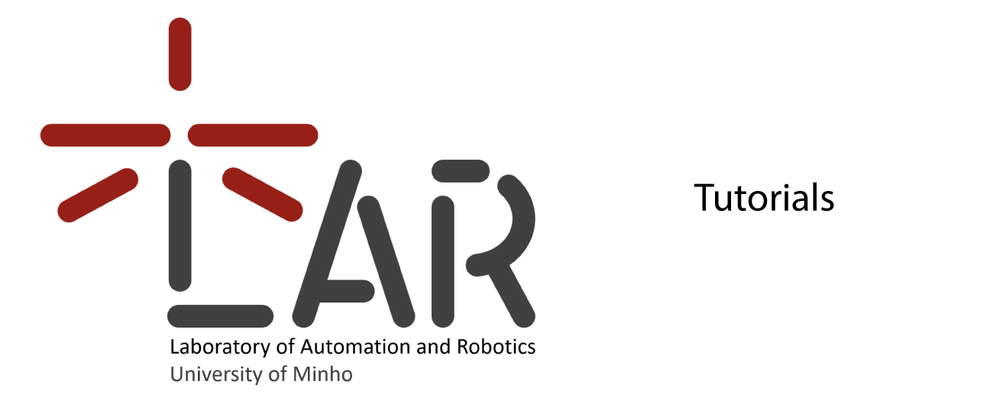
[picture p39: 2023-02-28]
Code/2023/Images/git_msl_tutorials.png

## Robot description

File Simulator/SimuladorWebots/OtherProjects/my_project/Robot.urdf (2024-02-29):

<?xml version="1.0"?>
<robot name="C:/Users/nandi/Desktop/Robot.urdf" xmlns:xacro="http://ros.org/wiki/xacro">
  <link name="base_link">
    <visual>
      <origin xyz="0 0 0.415" rpy="0 0 0"/>
      <geometry>
        <cylinder radius="0.45" length="0.8"/>
      </geometry>
    </visual>
    <collision>
      <origin xyz="0 0 0.415" rpy="0 0 0"/>
      <geometry>
        <cylinder radius="0.45" length="0.8"/>
      </geometry>
    </collision>
  </link>
  <joint name="motor2" type="continuous">
    <parent link="base_link"/>
    <child link="solid(1)"/>
    <axis xyz="-0.000005 1 -0.000002"/>
    <limit effort="10" velocity="10"/>
    <origin xyz="0 -0.5 0.05" rpy="-1.885625 1.570791 2.826762"/>
  </joint>
  <link name="solid(1)">
    <visual>
      <origin xyz="-0.06 0 0" rpy="0 0 0"/>
      <geometry>
        <cylinder radius="0.05" length="0.1"/>
      </geometry>
    </visual>
    <collision>
      <origin xyz="-0.06 0 0" rpy="0 0 0"/>
      <geometry>
        <cylinder radius="0.05" length="0.1"/>
      </geometry>
    </collision>
  </link>
  <joint name="motor1" type="continuous">
    <parent link="base_link"/>
    <child link="solid"/>
    <axis xyz="-0.000005 1 -0.000002"/>
    <limit effort="10" velocity="10"/>
    <origin xyz="-0.06 0.5 0.05" rpy="-1.885625 1.570791 2.826762"/>
  </joint>
  <link name="solid">
    <visual>
      <origin xyz="-0.06 0 0" rpy="0 0 0"/>
      <geometry>
        <cylinder radius="0.05" length="0.1"/>
      </geometry>
    </visual>
    <collision>
      <origin xyz="-0.06 0 0" rpy="0 0 0"/>
      <geometry>
        <cylinder radius="0.05" length="0.1"/>
      </geometry>
    </collision>
  </link>
</robot>

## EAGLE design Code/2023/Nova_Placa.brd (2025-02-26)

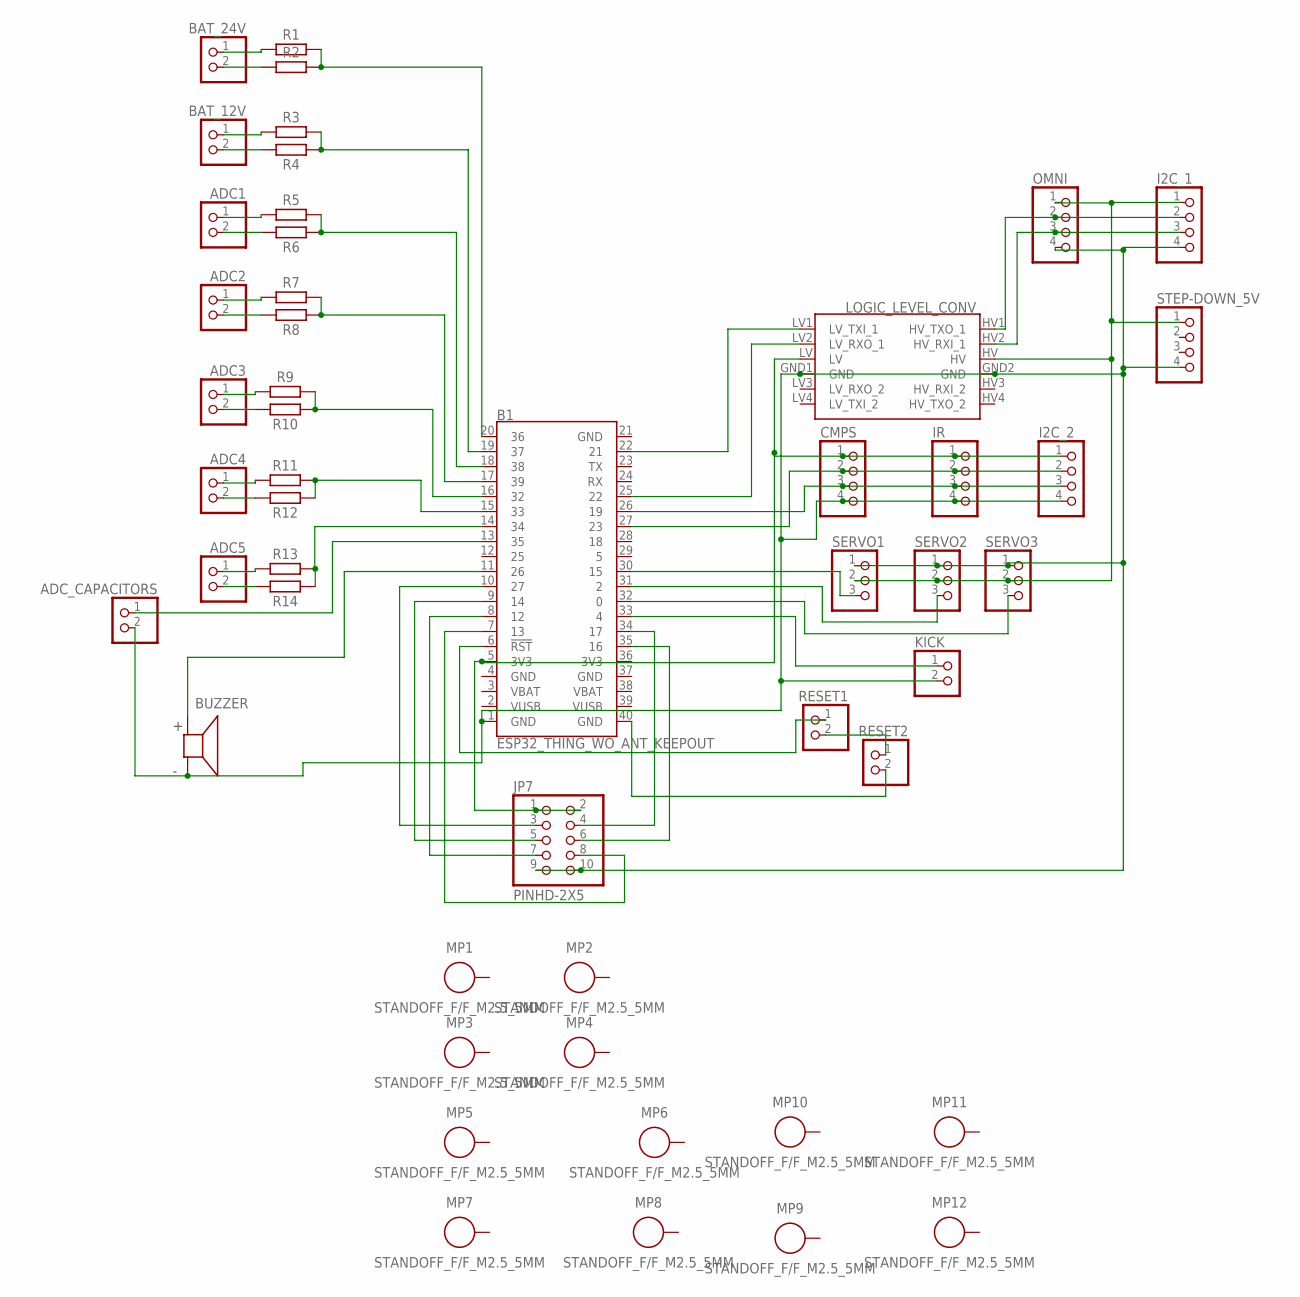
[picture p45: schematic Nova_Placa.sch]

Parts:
ADC1, ADC2, ADC3, ADC4, ADC5: PINHD-1X2; 1X02
ADC_CAPACITORS: PINHD-1X2; 1X02
B1: ESP32_THING_WO_ANT_KEEPOUT; ESP32_THING_NO_ANT
BAT_12V, BAT_24V: PINHD-1X2; 1X02
BUZZER: AT-1220-TT-9-R; XDCR_AT-1220-TT-9-R
CMPS: PINHD-1X4; 1X04
I2C_1, I2C_2: PINHD-1X4; 1X04
IR: PINHD-1X4; 1X04
JP7: PINHD-2X5; 2X05
KICK: PINHD-1X2; 1X02
LOGIC_LEVEL_CONV: SPARKFUN_LOGIC_LEVEL_CONVERTERLOCK; SPARKFUN_LOGIC_LEVEL_CONVERTER_LOCK
MP1, MP2, MP3, MP4, MP5, MP6, MP7, MP8, MP9, MP10, MP11, MP12: STANDOFF_F/F_M2.5_5MM; STANDOFF_HEX_FEMALE_500X500_M2.5X0.45_MTGP755H270
OMNI: PINHD-1X4; 1X04
R1, R2, R3, R4, R5, R6, R7, R8, R9, R10, R11, R12, R13, R14: R_AXIAL-7.2MM-PITCH; RESAD724W46L381D178B
RESET1, RESET2: PINHD-1X2; 1X02
SERVO1, SERVO2, SERVO3: PINHD-1X3; 1X03
STEP-DOWN_5V: PINHD-1X4; 1X04

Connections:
unnamed: B1.35 (16), JP7.6
unnamed: ADC_CAPACITORS.2, B1.1 (GND), BUZZER.N, CMPS.4, I2C_1.4, I2C_2.4, IR.4, JP7.9, JP7.10, KICK.2, LOGIC_LEVEL_CONV.GND1 (GND), LOGIC_LEVEL_CONV.GND2 (GND), OMNI.4, SERVO1.1, SERVO2.1, SERVO3.1, STEP-DOWN_5V.4
unnamed: B1.22 (21), LOGIC_LEVEL_CONV.LV1 (LV_TXI_1)
unnamed: B1.25 (22), LOGIC_LEVEL_CONV.LV2 (LV_RXO_1)
unnamed: B1.5 (3V3), CMPS.1, I2C_2.1, IR.1, JP7.1, JP7.2, LOGIC_LEVEL_CONV.LV
unnamed: I2C_1.1, LOGIC_LEVEL_CONV.HV, OMNI.1, SERVO1.2, SERVO2.2, SERVO3.2, STEP-DOWN_5V.1
unnamed: B1.27 (23), CMPS.2, I2C_2.2, IR.2
unnamed: B1.26 (19), CMPS.3, I2C_2.3, IR.3
unnamed: I2C_1.2, LOGIC_LEVEL_CONV.HV1 (HV_TXO_1), OMNI.2
unnamed: I2C_1.3, LOGIC_LEVEL_CONV.HV2 (HV_RXI_1), OMNI.3
unnamed: RESET1.2, RESET2.1
unnamed: B1.34 (17), JP7.4
unnamed: B1.7 (13), JP7.8
unnamed: B1.8 (12), JP7.7
unnamed: B1.9 (14), JP7.5
unnamed: B1.10 (27), JP7.3
unnamed: ADC5.1, R13.1
unnamed: ADC5.2, R14.1
unnamed: B1.14 (34), R13.2, R14.2
unnamed: ADC4.2, R12.1
unnamed: B1.15 (33), R11.2, R12.2
unnamed: ADC4.1, R11.1
unnamed: ADC3.2, R10.1
unnamed: ADC3.1, R9.1
unnamed: B1.16 (32), R9.2, R10.2
unnamed: ADC2.2, R8.1
unnamed: ADC2.1, R7.1
unnamed: B1.33 (4), KICK.1
unnamed: ADC1.2, R6.1
unnamed: ADC1.1, R5.1
unnamed: B1.18 (38), R5.2, R6.2
unnamed: BAT_12V.2, R4.1
unnamed: BAT_12V.1, R3.1
unnamed: B1.19 (37), R3.2, R4.2
unnamed: BAT_24V.2, R2.1
unnamed: BAT_24V.1, R1.1
unnamed: B1.20 (36), R1.2, R2.2
unnamed: B1.17 (39), R7.2, R8.2
unnamed: B1.32 (0), SERVO3.3
unnamed: B1.31 (2), SERVO2.3
unnamed: B1.30 (15), SERVO1.3
unnamed: B1.40 (GND), RESET2.2
unnamed: B1.11 (26), BUZZER.P
unnamed: ADC_CAPACITORS.1, B1.13 (35)
unnamed: B1.6 (!RST!), RESET1.1

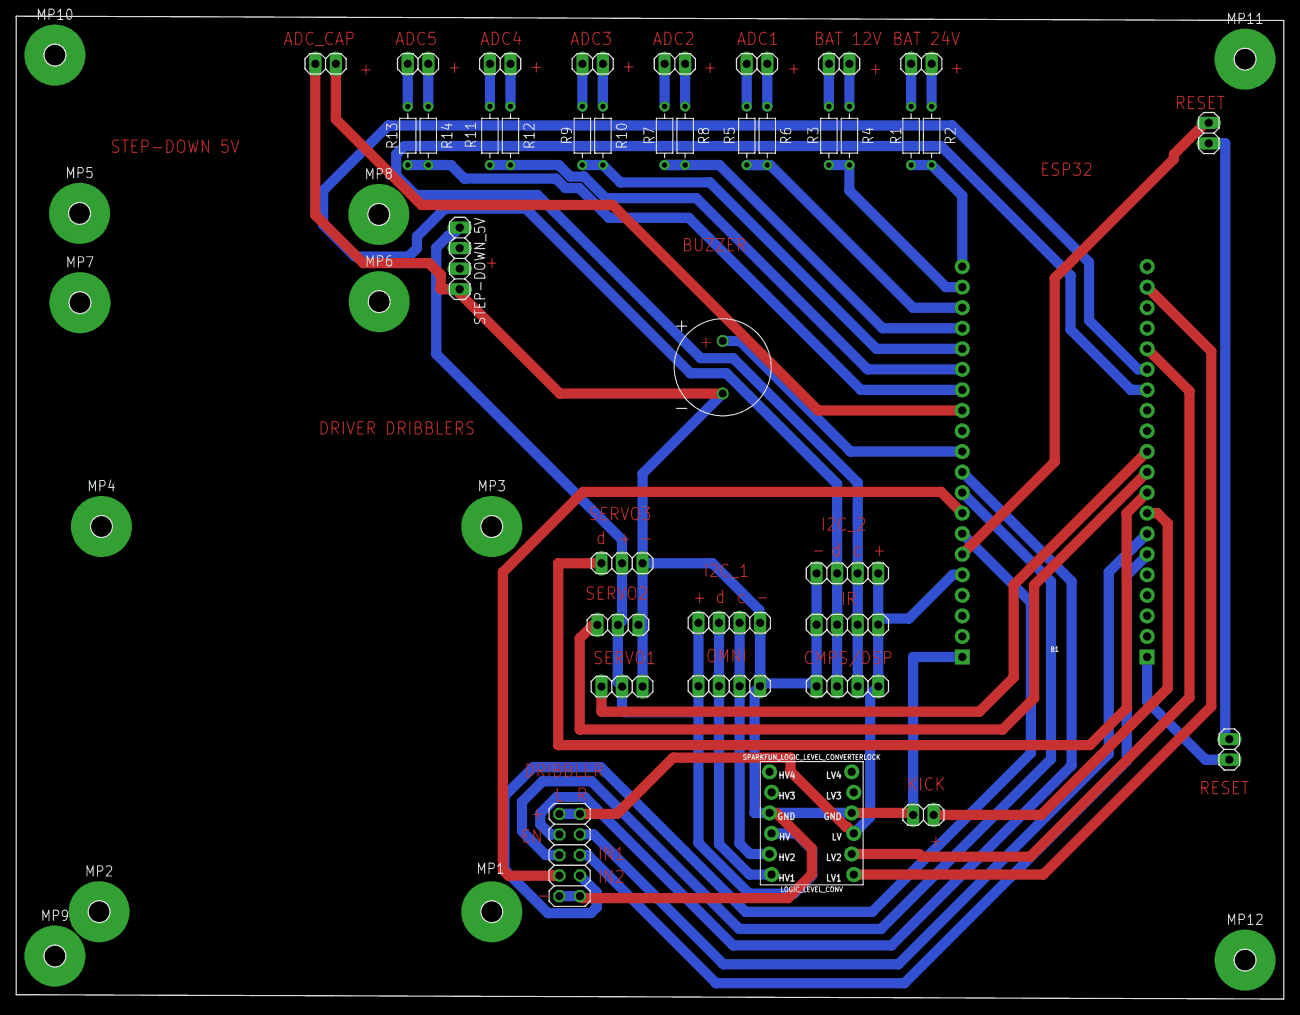
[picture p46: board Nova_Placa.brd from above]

Board: 2 copper layers, 156.7 x 121.5 mm, 50 parts (0 on the bottom side), 45 nets.

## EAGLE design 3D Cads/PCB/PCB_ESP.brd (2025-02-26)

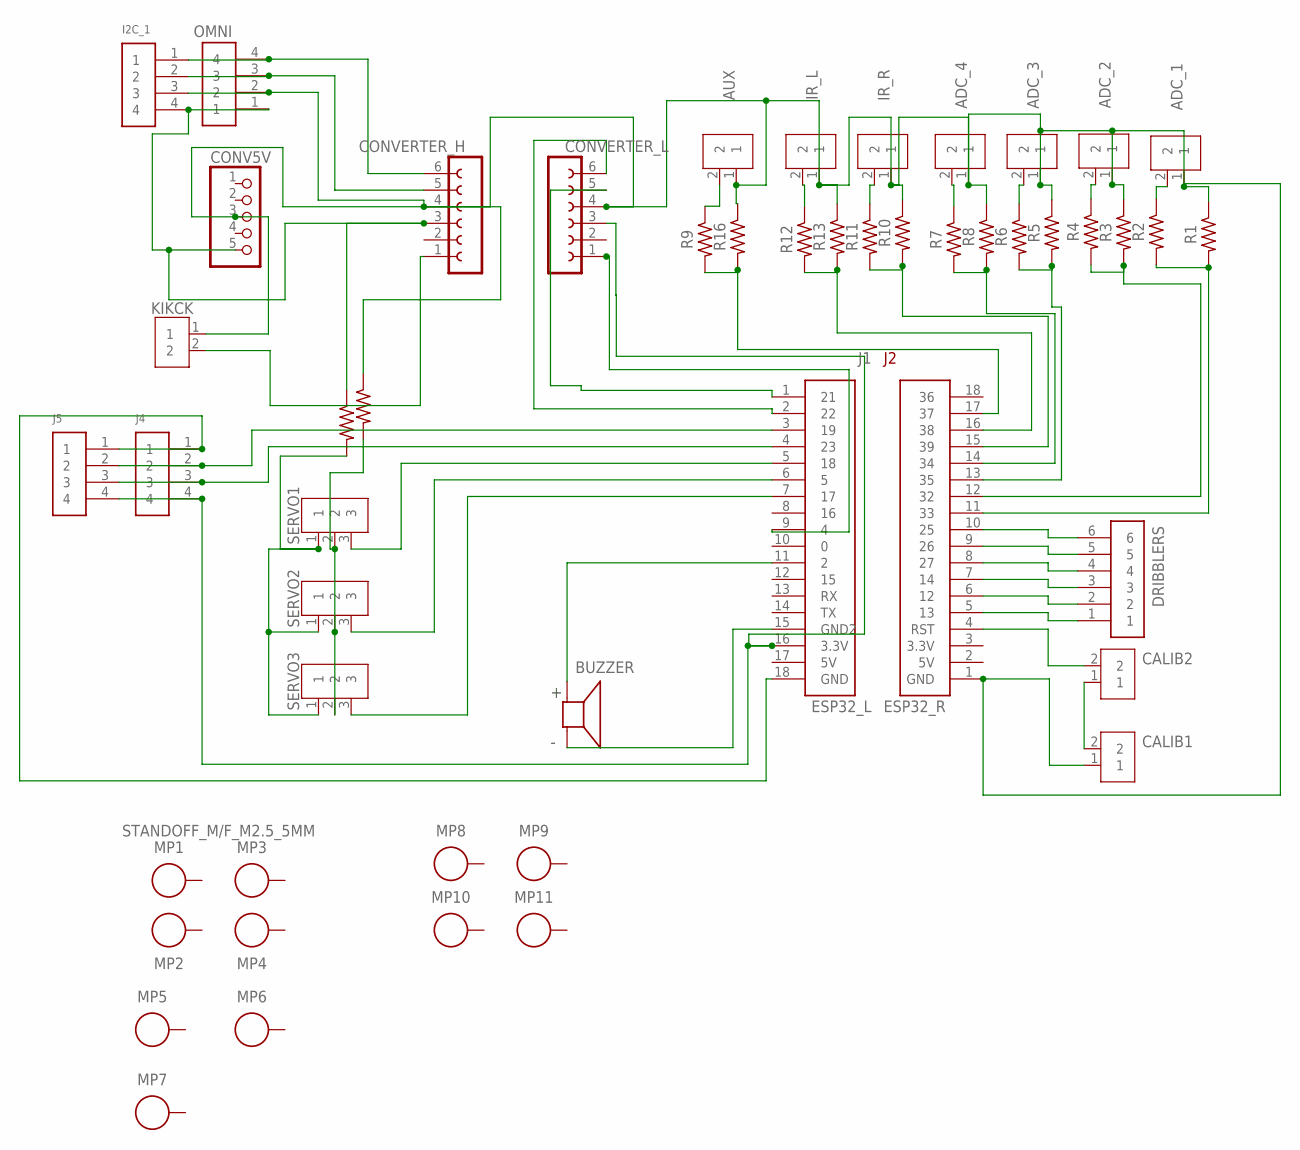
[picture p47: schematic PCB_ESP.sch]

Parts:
ADC_1, ADC_2, ADC_3, ADC_4: 2828XX-2282834-2; TERMBLK_254-2N
AUX: 2828XX-2282834-2; TERMBLK_254-2N
BUZZER: AT-1220-TT-9-R; XDCR_AT-1220-TT-9-R
CALIB1, CALIB2: 2828XX-2282834-2; TERMBLK_254-2N
CONV5V: PINHD-1X55X2MM; 1_05X2MM
CONVERTER_H: FE06-1; FE06
CONVERTER_L: FE06-1; FE06
DRIBBLERS: 61300611121
I2C_1: 61300411121
IR_L: 2828XX-2282834-2; TERMBLK_254-2N
IR_R: 2828XX-2282834-2; TERMBLK_254-2N
J1: ESP32_L; 61301811121
J2: ESP32_R; 61301811121
J4, J5: 61300411121
KIKCK: 2828XX-2282834-2; TERMBLK_254-2N
MP1, MP2, MP3, MP4, MP5, MP6, MP7: STANDOFF_M/F_M2.5_5MM; STANDOFF_HEX_MALE-FEMALE_500X500_M2.5X0.45_MTGP755H270
MP8, MP9, MP10, MP11: STANDOFF_F/F_M2.5_5MM; STANDOFF_HEX_FEMALE_500X500_M2.5X0.45_MTGP755H270
OMNI: 61300411121
R1, R2, R3, R4, R5, R6, R7, R8, R9, R10, R11, R12, R13, R14, R15, R16: R-US_AXIAL-7.2MM-PITCH; RESAD724W46L381D178B
SERVO1, SERVO2, SERVO3: 2828XX-3282834-3; TERMBLK_254-3N

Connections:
unnamed: DRIBBLERS.1, J2.5 (13)
unnamed: J2.12 (32), R3.2, R4.2
unnamed: ADC_2.2, R4.1
unnamed: CONVERTER_H.1, KIKCK.2
unnamed: CONVERTER_H.6, I2C_1.1, OMNI.4
unnamed: J2.14 (34), R7.2, R8.2
unnamed: CONVERTER_H.5, I2C_1.2, OMNI.3
unnamed: AUX.2, R9.1
unnamed: J2.13 (35), R5.2, R6.2
unnamed: CONVERTER_L.5, J1.1 (21)
unnamed: CONVERTER_L.6, J1.2 (22)
unnamed: ADC_4.2, R7.1
unnamed: BUZZER.N, J1.15 (GND2)
unnamed: ADC_3.2, R6.1
unnamed: CONV5V.5, CONVERTER_H.3, I2C_1.4, OMNI.1, R14.1
unnamed: BUZZER.P, J1.11 (2)
unnamed: ADC_1.1, ADC_2.1, ADC_3.1, ADC_4.1, AUX.1, CALIB1.1, CONV5V.3, CONVERTER_H.4, CONVERTER_L.4, I2C_1.3, IR_L.1, IR_R.1, J2.1 (GND), KIKCK.1, OMNI.2, R1.1, R3.1, R5.1, R8.1, R10.1, R13.1, R15.1, R16.1
unnamed: CALIB2.2, J2.4 (RST)
unnamed: DRIBBLERS.2, J2.6 (12)
unnamed: DRIBBLERS.3, J2.7 (14)
unnamed: DRIBBLERS.4, J2.8 (27)
unnamed: DRIBBLERS.5, J2.9 (26)
unnamed: DRIBBLERS.6, J2.10 (25)
unnamed: CALIB1.2, CALIB2.1
unnamed: ADC_1.2, R2.1
unnamed: CONVERTER_L.1, J1.9 (4)
unnamed: J2.11 (33), R1.2, R2.2
unnamed: J2.15 (39), R10.2, R11.2
unnamed: IR_L.2, R12.1
unnamed: IR_R.2, R11.1
unnamed: J1.18 (GND), J4.1, J5.1
unnamed: J2.17 (37), R9.2, R16.2
unnamed: J2.16 (38), R12.2, R13.2
unnamed: R14.2, SERVO1.1, SERVO2.1, SERVO3.1
unnamed: R15.2, SERVO1.2, SERVO2.2, SERVO3.2
unnamed: J1.5 (18), SERVO1.3
unnamed: J1.6 (5), SERVO2.3
unnamed: J1.7 (17), SERVO3.3
unnamed: J1.3 (19), J4.2, J5.2
unnamed: J1.4 (23), J4.3, J5.3
unnamed: CONVERTER_L.3, J1.16 (3.3V), J4.4, J5.4

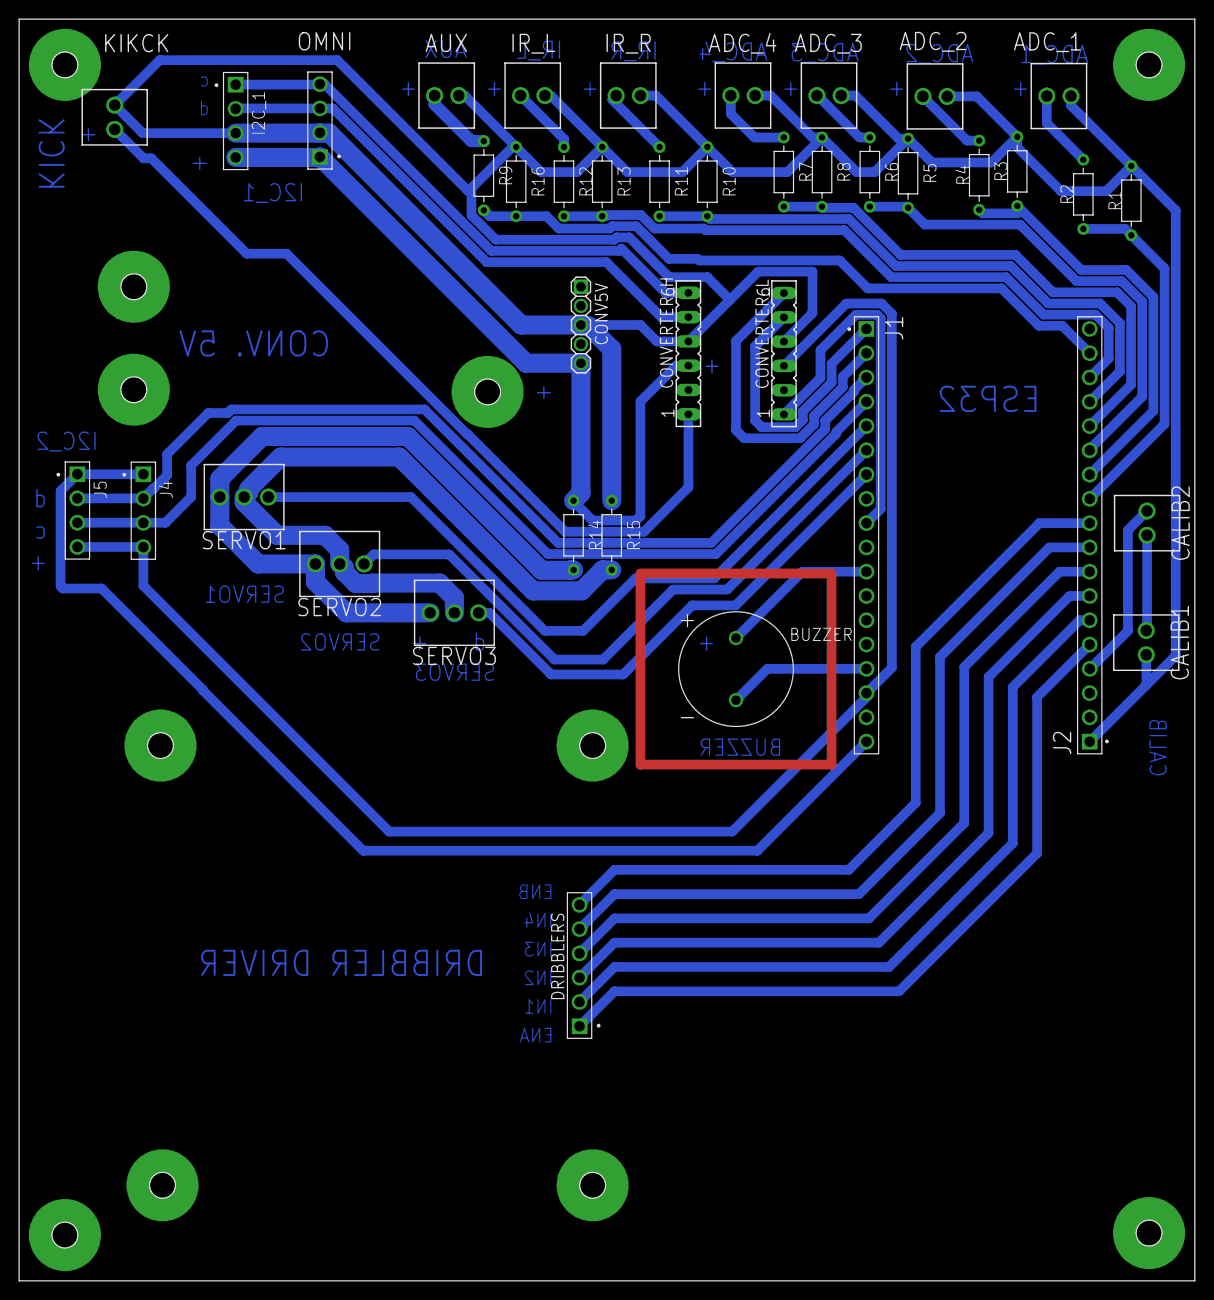
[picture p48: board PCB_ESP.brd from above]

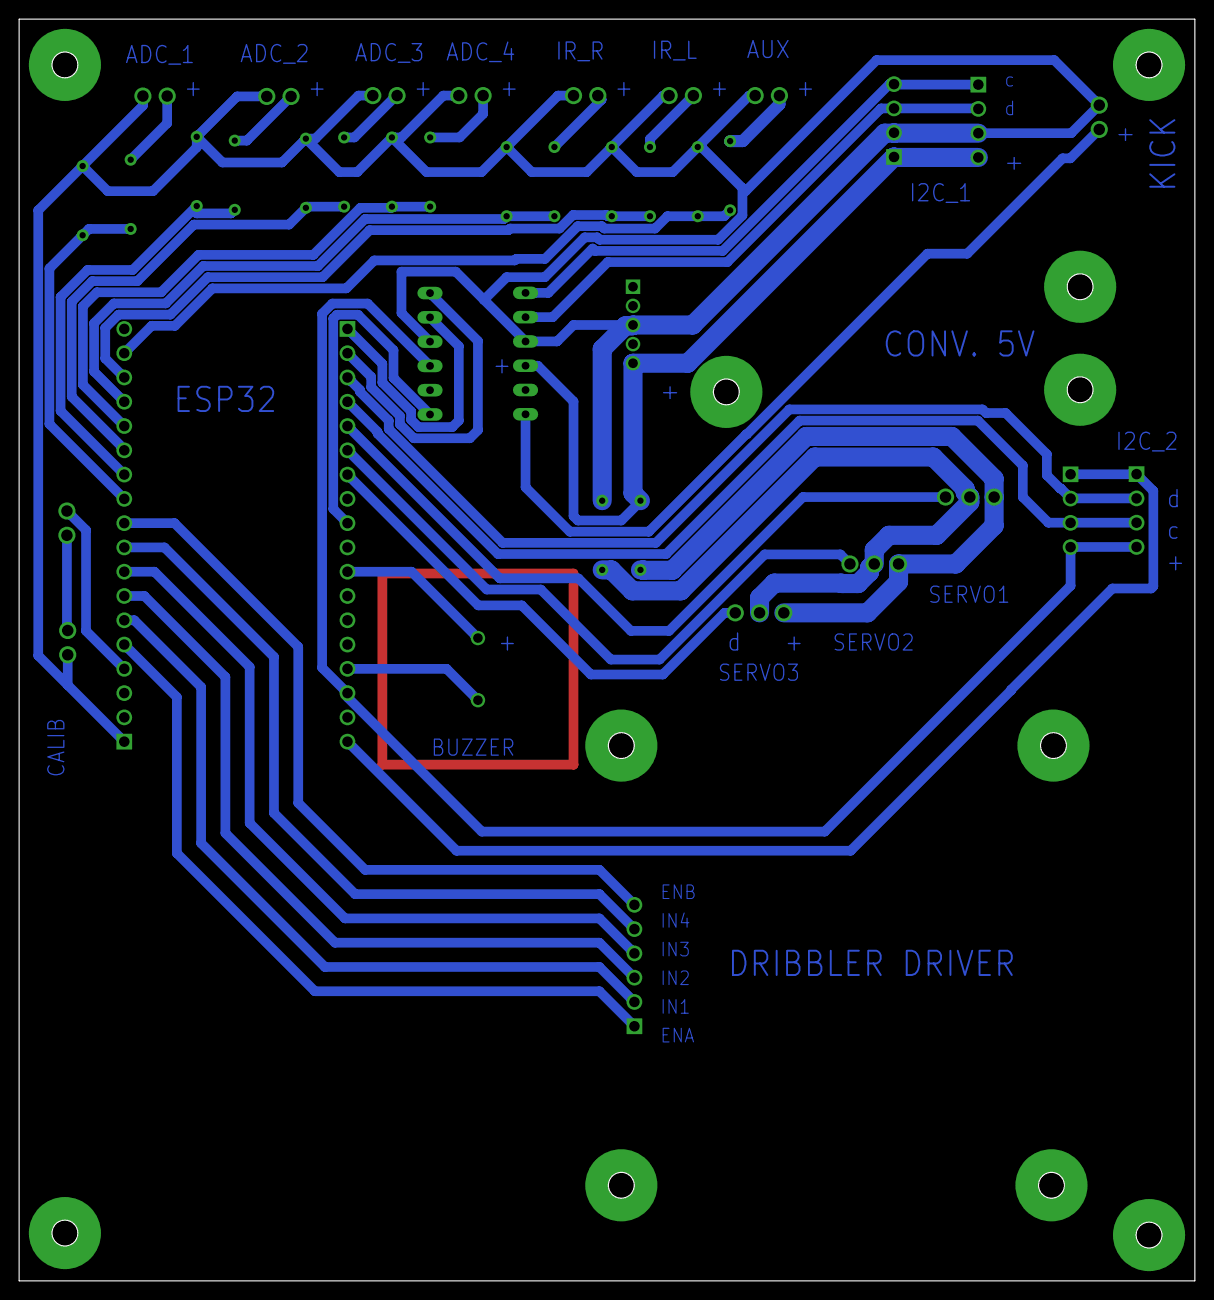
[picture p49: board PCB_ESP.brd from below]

Board: 2 copper layers, 123.0 x 132.0 mm, 51 parts (4 on the bottom side), 41 nets.

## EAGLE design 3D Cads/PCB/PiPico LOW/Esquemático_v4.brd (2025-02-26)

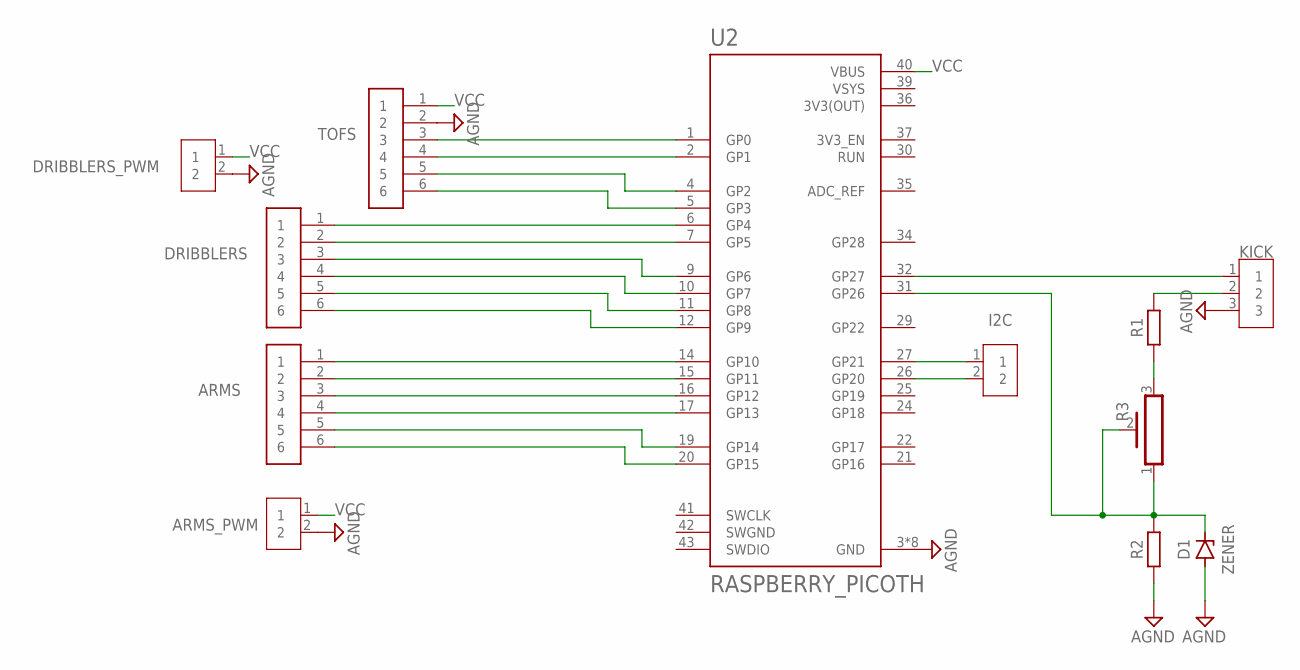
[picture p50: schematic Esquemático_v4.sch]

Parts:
ARMS: 691311400106; TERMINALBLOCK_PLUGGABLE-6-7.62MM
ARMS_PWM: 2828XX-2282834-2; TERMBLK_254-2N
D1: ZENER; DIOM7959X625N
DRIBBLERS: 691311400106; TERMINALBLOCK_PLUGGABLE-6-7.62MM
DRIBBLERS_PWM: 2828XX-2282834-2; TERMBLK_254-2N
I2C: 2828XX-2282834-2; TERMBLK_254-2N
KICK: 2828XX-3282837-3; TERMBLK_508-3N
R1, R2: R_AXIAL-7.2MM-PITCH; RESAD724W46L381D178B
R3: PV36Z
TOFS: 691311400106; TERMINALBLOCK_PLUGGABLE-6-7.62MM
U2: RASPBERRY_PICOTH; PICO-PKG-TH

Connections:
3V3(OUT): U2.36 (3V3(OUT))
AGND: ARMS_PWM.2, D1.2 (A), DRIBBLERS_PWM.2, KICK.3, R2.1, TOFS.2, U2.3 (GND), U2.8 (GND), U2.13 (GND), U2.18 (GND), U2.23 (GND), U2.28 (GND), U2.33 (GND), U2.38 (GND)
KICK: TOFS.4, U2.2 (GP1)
unnamed: DRIBBLERS.1, U2.6 (GP4)
unnamed: TOFS.6, U2.5 (GP3)
unnamed: TOFS.5, U2.4 (GP2)
unnamed: DRIBBLERS.2, U2.7 (GP5)
unnamed: DRIBBLERS.3, U2.9 (GP6)
unnamed: DRIBBLERS.4, U2.10 (GP7)
unnamed: DRIBBLERS.5, U2.11 (GP8)
unnamed: DRIBBLERS.6, U2.12 (GP9)
unnamed: ARMS.1, U2.14 (GP10)
unnamed: ARMS.2, U2.15 (GP11)
unnamed: ARMS.3, U2.16 (GP12)
unnamed: ARMS.4, U2.17 (GP13)
unnamed: ARMS.5, U2.19 (GP14)
unnamed: ARMS.6, U2.20 (GP15)
unnamed: KICK.1, U2.32 (GP27)
unnamed: KICK.2, R1.2
unnamed: D1.1 (C), R2.2, R3.1, R3.2, U2.31 (GP26)
unnamed: I2C.1, U2.27 (GP21)
unnamed: I2C.2, U2.26 (GP20)
unnamed: R1.1, R3.3
SWGND: U2.42 (SWGND)
TOF_SDA: TOFS.3, U2.1 (GP0)
VCC: ARMS_PWM.1, DRIBBLERS_PWM.1, TOFS.1
VSYS: U2.39 (VSYS)

Board: 2 copper layers, 12 parts (1 on the bottom side), 24 nets, no tracks yet.

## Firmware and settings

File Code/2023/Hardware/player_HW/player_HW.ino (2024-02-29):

#if !defined( ESP32 )
  #error This code is intended to run on the ESP32 platform! Please check your Tools->Board setting.
#endif

#include <Wire.h>                   // required by Omni3MD.cpp
#include <BnrOmni.h>
#include <string.h>
#include <SPI.h>
#include "Arduino.h"
#include <DabbleESP32.h>
#include <Timeout.h>

#include <Adafruit_GFX.h>
#include <Adafruit_SSD1306.h>


#define CUSTOM_SETTINGS
#define INCLUDE_GAMEPAD_MODULE
#define REMOTE_CONTROL // Uncomment if you want to control remotly via BT

//odometry constants
#define SEN60 0.8660254038
#define COS60 0.5
#define To_mm 0.1112 //ticks to mm
#define To_rad 0.017453293 //ticks to mm

//I2C commands for CMPS14 sensor
#define BEARING_Register 2 
#define PITCH_Register 4 
#define ROLL_Register 5

#define MAGNETX_Register  6
#define MAGNETY_Register  8
#define MAGNETZ_Register 10

#define ACCELEROX_Register 12
#define ACCELEROY_Register 14
#define ACCELEROZ_Register 16

#define GYROX_Register 18
#define GYROY_Register 20
#define GYROZ_Register 22

#define CALIB_Register 30

#define ONE_BYTE   1
#define TWO_BYTES  2
#define FOUR_BYTES 4
#define SIX_BYTES  6

//I2C communication pins for CMPS14 sensor 
#define CMPS14_Address 0x60
#define SDA_CMPS14 19
#define SCL_CMPS14 23


//I2C communication address for display
#define SCREEN_ADDRESS 0x3C ///< See datasheet for Address; 0x3D for 128x64, 0x3C for 128x32

#define SCREEN_WIDTH 128 // OLED display width, in pixels
#define SCREEN_HEIGHT 32 // OLED display height, in pixels

#define OLED_RESET     -1 // Reset pin # (or -1 if sharing Arduino reset pin)


//I2C communication pins for OMNI driver
#define  SDA_OMNI 21
#define SCL_OMNI 22
//I2C communication address for OMNI driver
#define OMNI3MD_ADDRESS 0x30
#define OMNI_COM_TIMEOUT 0

//OMNI motors constants
#define M1 1
#define M2 2
#define M3 3


//driblers control pins
#define IN2 12  //direction of rotation control for motor A
#define IN1 14  //direction of rotation control for motor A
#define IN3 16  //direction of rotation control for motor B
#define IN4 13  //direction of rotation control for motor B
#define PWM1 17 //PWM to control speed of motor A
#define PWM2 27 //PWM to control speed of motor B
#define ADC12 37  //ADC 12 V
#define ADC24 36  //ADC 24 V

#define ENABLE_DB 5 //3.3V power for gpio control
#define db1_channel 0
#define db2_channel 1

//Kick pin
#define KICK 4

#define TIMER0_INTERVAL_MS        1000
#define TIMER0_DURATION_MS        0//5000

#define TIMER1_INTERVAL_MS        30
#define TIMER1_DURATION_MS        0//5000
#define PWM1_Ch 0
#define PWM2_Ch 1

#define LAST_COM_TIMEOUT        50
#define LED 5



//Declaration of object variable to control the Omni3MD
BnrOmni omni; 
 
//Declaration of object variable to communicate with CPS14 via I2C         
TwoWire CMPS14= TwoWire(1);
 
//#define SCREEN_WIDTH 128 // OLED display width, in pixels
//#define SCREEN_HEIGHT 64 // OLED display height, in pixels

// Declaration for an SSD1306 display connected to I2C (SDA, SCL pins)
#define OLED_RESET     -1 // Reset pin # (or -1 if sharing Arduino reset pin)
#define SCREEN_ADDRESS 0x3C ///< See datasheet for Address; 0x3D for 128x64, 0x3C for 128x32
Adafruit_SSD1306 display(SCREEN_WIDTH, SCREEN_HEIGHT, &CMPS14, OLED_RESET);

#define NUMFLAKES     10 // Number of snowflakes in the animation example

#define LOGO_HEIGHT   16
#define LOGO_WIDTH    16


int serial_communication_time = 0;
int communication_time = 0;

//Actuation variables for OMNI
int linear_sp= 0;    // 0 to 100
int direction_sp= 0;   // 0 to 360
int rotational_sp=0; // -100 to 100

int omni_Kp = 0;
int omni_Ki = 0;
int omni_Kd = 0;

int last_enc1 = 0;
int last_enc2 = 0;
int last_enc3 = 0;

float omni_temperature = 0.0;
float omni_battery = 0.0;
  
//Actuation speed for dribler motors
int dribler1_vel= 0;   // 0 to 100  speed for motor 1 from dribler
int dribler2_vel= 0;    // 0 to 100

int maxKick = 35;
hw_timer_t *Kick_timer = NULL;
const int wdtTimeout = 3000;  //time in ms to trigger the watchdog

String command;
 
bool negative=false;
int   count_KICK=0;
uint32_t currTime=0;
uint32_t InterruptTime=0;
bool Kick_end=false;

uint32_t last_communication_time=0;
uint32_t last_time=0;

int angle_reference=0;

bool send_package=false;
/*
  *
  ball_possession_stage defines the distance between ball and dribblers
  0 -> no distance between ball and rollerback (inside dribblers)
  1 -> ball entering in dribblers
  2 -> ball completely out of dribblers
  *
*/

int ball_possession_stage=0;
 
float accelScale = 9.80592991914f/1000.f; // 1 m/s^2

String up_str ="12,0,34,45,45,0";
String bat_str ="";

String inputString = "";         // a String to hold incoming data
bool stringComplete = false;  // whether the string is complete

Timeout omni_com_timeout;
bool omni_com_failure=false;

#ifdef REMOTE_CONTROL
  bool START=false;
  int speed_= 0;
  int direction_= 0;
  int rotational_=0;
  #endif
 
void InitOMNI(){
  byte _omniAddress = OMNI3MD_ADDRESS>>1;
  Wire.begin(SDA_OMNI,SCL_OMNI);
  delay(10);                          // pause 10 milliseconds
   omni.i2cConnect(OMNI3MD_ADDRESS);  // set i2c connection
  delay(10);                               
   omni.stop();                 // stops all motors
  delay(30);
   omni.setI2cTimeout(OMNI_COM_TIMEOUT); // safety parameter -> I2C communication must occur every [byte timeout] x 100 miliseconds for motor movement                             
  delay(20);                 // 5ms pause required for Omni3MD eeprom writing
                       // 5ms pause required for Omni3MD eeprom writing
  omni.setMinBat(9.7);
 // Serial.println("aqui4");
  delay(10);
  omni.setPid(1000, 50, 0);
  delay(10);
  omni.setRamp(50, 1000);
  delay(10);
 
}


void InitCMPS14(){
 
  CMPS14.begin(SDA_CMPS14, SCL_CMPS14);  
  //CMPS14.setTimeout(10000);
 
  delay(20);

}

void InitDriblers(){

  pinMode(IN1, OUTPUT); 
  pinMode(IN2, OUTPUT);
  pinMode(IN3, OUTPUT);
  pinMode(IN4, OUTPUT);
  pinMode(PWM1, OUTPUT);
  pinMode(PWM2, OUTPUT);
  //ledcSetup(db1_channel, 5000, 8);
  //ledcSetup(db2_channel, 5000, 8);

  // Attach the channel 0 on the 3 pins
  //ledcAttachPin(PWM1, db1_channel);
   //ledcAttachPin(PWM2, db2_channel);
 
  
  digitalWrite(IN1, LOW);   // turn the LED on (HIGH is the voltage level)
  digitalWrite(IN2, LOW);   // turn the LED on (HIGH is the voltage level)
  digitalWrite(IN3, LOW);   // turn the LED on (HIGH is the voltage level)  
  digitalWrite(IN4, LOW);   // turn the LED on (HIGH is the voltage level)
 
   pinMode(ENABLE_DB, OUTPUT);
   digitalWrite(ENABLE_DB, HIGH);
  //add PWM pins
}

void Initkick(){
  pinMode(KICK, OUTPUT);
  digitalWrite(KICK, LOW);

    
}

void InitMonitor(){
// Clear the buffer
  ledcSetup(5, 1500, 8);

  // Attach the channel 0 on the 3 pins
  ledcAttachPin(26, 5);
  ledcWrite(5, 0);
 if(!display.begin(SSD1306_SWITCHCAPVCC, SCREEN_ADDRESS)) {
    Serial.println(F("SSD1306 allocation failed"));
    for(;;); // Don't proceed, loop forever
  }
  

  // Show initial display buffer contents on the screen --
  // the library initializes this with an Adafruit splash screen.
  display.display();
  delay(20); // Pause for 2 seconds

 
}
 
 
 
void setup() {
  //setup routines
  Serial.begin(115200);               // set baud rate to 115200bps for printing values in serial monitor. Press (ctrl+shift+m) after uploading
  Dabble.begin("Robot4_ESP");       //set bluetooth name of your device
  
  inputString.reserve(150);
  pinMode(LED,OUTPUT);
 
  InitDriblers();
  InitOMNI();
  InitCMPS14();
  Initkick();
  InitMonitor();

  getBearingReference();
 Serial.println("End Of Setup");
  #ifdef REMOTE_CONTROL
     Serial.println("Entrou");
  #endif
}

 
String GetLastCommand(String& buffer) {
  // Split the incoming serial data into individual commands using '\n' as the delimiter
  int last_index = buffer.lastIndexOf('\n');
  if (last_index == -1) {
    // No complete commands in the buffer yet
    return "";
  }
  bool char_found=false;
  char caracter;
  int first_index=last_index;
  while (!char_found && first_index>=0){//(caracter) <  65 && (caracter) > 90)
    
    caracter=buffer.charAt(first_index);
    if(isAlpha(caracter)){
      char_found=true;
     
    }
    first_index--;
  }
  first_index++;
  if (!char_found || (last_index-first_index>24)){
    return "";
  }
  //Serial.print("\n\nfirst_index:  ");Serial.print(first_index);
  //Serial.print("  last_index  ");Serial.println(last_index);
  
  String last_command = buffer.substring(first_index,last_index + 1);
 // last_command.remove(last_index + 1);
   //Serial.print("last_command:  ");Serial.println(last_command);
  // Return the last command if it is valid (i.e., starts with a letter and ends with '\n')
  
  if (last_command.length() > 1 && isAlpha(last_command.charAt(0)) && last_command.charAt(last_command.length() - 1) == '\n') {
    //Serial.println("return last_command ");
    return last_command;
  } else {
    //Serial.println("return \"\"  ");Serial.println(int(last_command.charAt(last_command.length() - 1)));
    return "";
  }
 }
String get_last_command(String input) {
  int last_newline_index = input.lastIndexOf("\n");
  if (last_newline_index >= 0) {
    return input.substring(last_newline_index + 1);
  } else {
    return "";
  }
}
void loop() {
 
   UpdateTableMonitor();
  if(Kick_end){
    Kick_end=false;
    //Serial.print("kick Time:\t");
    //Serial.println(InterruptTime- currTime);
  }
   
  if(millis()-last_communication_time>LAST_COM_TIMEOUT)
  {
   // Serial.print("Commands TIMEOUT:\t\n");
    //omni.stop_motors();
    //.UpdateDriblerParameters(0,0);
    SendPackage();
    last_communication_time = millis();
 
  } 
  
  if(stringComplete) {
    stringComplete=false;
    communication_time = millis();
    
    command = GetLastCommand(inputString);//GetLastCommand(inputString);
      
    if(command!=""){
      int i=0;
      last_communication_time = millis();
    
      switch(command[0]){
        case 'p':
        case 'P' :{   //case the first byte is P sets the omni control parameters                              
           
          String str_kp = GetValues(command, 1);
          String str_ki = GetValues(command, 2);
          String str_kd = GetValues(command, 3);
          Serial.print("\n  kp: ");Serial.print(str_kp);
          Serial.print("  ki: ");Serial.print(str_ki);
          Serial.print("  kd: ");Serial.println(str_kd);
                  

          SetOmniControl(str_kp.toInt(),str_ki.toInt(),str_kd.toInt());
        }
        break;
        case 'r':
        case 'R' :{   //case the first byte is P sets the omni control parameters                              
           
          String str_time = GetValues(command, 1);
          String str_slope = GetValues(command, 2);
          String str_kl = GetValues(command, 3);
          Serial.print("\n  time: ");Serial.print(str_time);
          Serial.print("  slope: ");Serial.print(str_slope);
          Serial.print("  kl: ");Serial.println(str_kl);
          omni.setRamp(str_slope.toInt(),str_kl.toInt());
        }
        break;
        case 'd':
        case 'D' :{    //case the first byt is W it controls only the rotational speed                              
           
          String db1 = GetValues(command, 1); 
          String db2 = GetValues(command, 2); 
         
          UpdateDriblerParameters(db1.toInt(),db2.toInt());
  
        }
        break;
        case 'm':
        case 'M' :{   //case the first byt is R it controls linear, rotational speed and direction                              
           
          String lin_aux = GetValues(command, 1); 
          String rot_aux = GetValues(command, 2); 
          String dir_aux = GetValues(command, 3); 
          
          UpdateOmniParameters(lin_aux.toInt(),rot_aux.toInt(),dir_aux.toInt());
  
        }
        break;
        case 'c':
        case 'C':{    //by default the esp receives a package with the values for update
          String linear_vel = GetValues(command, 1);
          String rotat_vel = GetValues(command, 2);
          String direcao = GetValues(command, 3);
          
          String dribler1 = GetValues(command, 4);
          String dribler2 = GetValues(command, 5);
          
          String kick_time= GetValues(command, 6);  
              
          UpdateOmniParameters(linear_vel.toInt(),rotat_vel.toInt(),direcao.toInt());
         /* Serial.print("\n  linear_vel: ");Serial.print(linear_vel);
          Serial.print("  rotat_vel: ");Serial.print(rotat_vel);
          Serial.print("  direcao: ");Serial.println(direcao);
          Serial.print("\n  dribler1: ");Serial.print(dribler1);
          Serial.print("  dribler2: ");Serial.print(dribler2);
          Serial.print("  kick_time ");Serial.println(kick_time);*/
          UpdateDriblerParameters(dribler1.toInt(),dribler2.toInt());
          if (kick_time.toInt() > 0)
          {
            UpdateKickParameters(kick_time.toInt());
          }
           
         }
        break;
        default:
        break;
      }
      
    }
  



 
  }

  #ifdef REMOTE_CONTROL
     Dabble.processInput();             //this function is used to refresh data obtained from smartphone.Hence calling this function is mandatory in order to get data properly from your mobile.
 
 
  bool STARTPRESED=false;
  if (GamePad.isStartPressed())
  {
    while(!STARTPRESED){STARTPRESED=GamePad.isStartPressed();}
    Serial.println("Start");
    START = START ? false:true;
    omni.movOmni(0,0,0);
  }
  if (START)
  { 
    //Serial.println("START");
    int angle = GamePad.getAngle(); 
       
    int vel = GamePad.getRadius();

    if (GamePad.isCirclePressed()){
      if(GamePad.isCirclePressed()==0);
      rotational_=5;
    }
    //Serial.println(GamePad.isSquarePressed());
    if (GamePad.isSquarePressed()){ 
      rotational_=-5;
    }
    if (GamePad.isTrianglePressed()){ 
      rotational_=0;
      //Serial.print("isTrianglePressed");
    }
    if (GamePad.isCrossPressed())
    {
      UpdateKickParameters(8);
      UpdateDriblerParameters(0,0);
      //Serial.print("isCrossPressed");
    }
    if (GamePad.isUpPressed())
    {
        angle = 90;
        vel = 100;
    }
    if (GamePad.isDownPressed())
    {
        angle = -90;
        vel = 100;
    }
    if (GamePad.isRightPressed())
    {
        angle = 180;
        vel = 100;
    }
    if (GamePad.isLeftPressed())
    {
        angle = 0;
        vel = 100;
    }
    if (GamePad.isSelectPressed())
    {
      UpdateDriblerParameters(255,255);
    }

    angle-=90;
    if (angle<0){
     angle+=360;
     
    }
  
    if (angle>=0 && angle <=360)
      direction_=angle;
   
    speed_=vel*10;
     
    if (speed_ <= 0){
      speed_=0;
    }
    if (speed_ > 90){
      speed_=100;
    }
    
    
    if(rotational_>90){
      rotational_=90;
    }
    
    if(rotational_<-90){
      rotational_=-90;
    }
    UpdateOmniParameters(speed_,rotational_,direction_);
    //omni.mov_omni(speed_,rotational_,direction_);
    }
  #endif
    //Serial.print(" time="  );
  //Serial.println(millis()-last_time);
  //last_time=millis();

  //String package = String(speed_) + " "  + String(rotational_) + " " + String(direction_) + "\t";
  //Serial.println(package);
}
 
void serialEvent() {
  while (Serial.available()) {
    // get the new byte:
    char inChar = (char)Serial.read();
    // add it to the inputString:
    inputString += inChar;
    // if the incoming character is a newline, set a flag so the main loop can
    // do something about it:
    if (inChar == '\n') {
      //Serial.print(inputString.length());
      if (inputString.length()>150){
        inputString="";
        Serial.flush();
      }else{
        stringComplete = true;
      }
    }  
  }
}
void odometry(int robot_angle,int* xd, int* yd){
    // Degrees to Radians
    float  rad_y_angle=robot_angle*To_rad;
    float  rad_x_angle=(robot_angle-90)*To_rad;
    // Read Encoders
   // omni_com_timeout.start(30);
     int16_t  enc1=0;                
    int16_t enc2=0;                 
    int16_t enc3=0;                 
    int start = millis(); 
  
    enc1=(int16_t)omni.readEnc1();                // read encoder1 count value for the defined prescaler (positional control)
    //Serial.println(!omni_com_timeout.time_over());
   // Serial.print("read odometry0.5=  ");Serial.println(millis()-start); 
    //if(!omni_com_timeout.time_over()){
     // omni_com_failure=false;
      enc2=(int16_t)omni.readEnc2();                // read encoder1 count value for the defined prescaler (positional control)
    //}else{
    ///  omni_com_failure=true;
    //}
    //Serial.println(!omni_com_timeout.time_over());
    //if(!omni_com_timeout.time_over()){
    //  omni_com_failure=false;
      enc3=(int16_t)omni.readEnc3();                // read encoder1 count value for the defined prescaler (positional control)
    ////}else{
     // omni_com_failure=true;
    //}
   // Serial.print("read odometry=  ");Serial.println(millis()-start); 
    start = millis(); 
    /*Serial.print("enc1:");
    Serial.print(enc1);           // prints encoder 1 positional value
    Serial.print(" enc2:");
    Serial.print(enc2);           // prints encoder 2 positional value
    Serial.print(" enc3:");
    Serial.println(enc3); */ 
    // Reset Encoders    
    omni.setEncValue(M1,0);
        omni.setEncValue(M2,0);
 
     omni.setEncValue(M3,0);
     
        


      start = millis(); 
    
    // Delta Position Robot
    float  y_r = ((enc3-enc1)/(2*SEN60));
    float  x_r = (((enc2*2)-enc1-enc3)/(2*(COS60+1)));
     /*Serial.print(" X_R:");
     Serial.print(x_r);           // prints encoder 2 positional value
     Serial.print(" Y_R:");
     Serial.println(y_r); */
    // Delta Position Field
    *xd = (y_r*cos(rad_y_angle)+ x_r*cos(rad_x_angle))*To_mm;
    *yd = (y_r*sin(rad_y_angle)+ x_r*sin(rad_x_angle))*To_mm;
}
 
void UpdateOmniParameters(int lin, int rot, int dir){
    //linear velocity varies between 0 and 100
    linear_sp = (lin <= 100 && lin >= 0 ) ? lin : linear_sp;
    //rotational velocity varies between -100 and 100
    rotational_sp = (rot <= 100 && rot >= -100)? rot : rotational_sp ;
    //direction varies between 0 and 360
    direction_sp = (dir < 360 && dir >= 0)? dir : direction_;
    /*Serial.print("\nlin  ");  Serial.print(linear_sp);
    Serial.print("    rot  ");  Serial.print(rotational_sp );
    Serial.print("    dir  ");  Serial.println(direction_sp );*/
    
   
    omni.movOmni(linear_sp ,rotational_sp ,direction_sp );
 
}
void UpdateDriblerParameters(int M1_, int M2_){
  //speed of the driblers can go from -100 to 100
  
  dribler1_vel= M1_;   // 0 to 100  speed for motor 1 from dribler
  dribler2_vel= M2_;  
  if(M1_ > 100){
    dribler1_vel=100;
  }
  else if(M1_ < -100){
    dribler1_vel=-100;    
  }
  if(M2_ > 100){
    dribler2_vel=100;
  }
  else if(M2_ < -100){
    dribler2_vel=-100;
  }
  

  if(M1_ >= 0){
    //digitalWrite(PWM1, HIGH);
    digitalWrite(IN1, HIGH);
    digitalWrite(IN2, LOW);
    analogWrite(PWM1, (dribler1_vel*2.5));
    //ledcWrite(db1_channel, dribler1_vel);
  }
   else if(M1_ < 0){
    //digitalWrite(PWM1, HIGH);
    digitalWrite(IN1, LOW);
    digitalWrite(IN2, HIGH);
    analogWrite(PWM1, -dribler1_vel*2.5);
    //ledcWrite(db1_channel, -dribler1_vel);
  } 
  
  if(M2_ >= 0){
    //digitalWrite(PWM2, HIGH);
    digitalWrite(IN3, HIGH);
    digitalWrite(IN4, LOW);
    //Serial.println("OURUOUTOTU  ");
   // ledcWrite(db2_channel, dribler2_vel);
    analogWrite(PWM2, (dribler2_vel));
    //analogWrite(PWM2, 255);
    //delay(10);
  } 
  else if(M2_ < 0){
    //digitalWrite(PWM2, HIGH);
    digitalWrite(IN3, LOW);
    digitalWrite(IN4, HIGH);
    analogWrite(PWM2, -dribler2_vel);
   // ledcWrite(db2_channel, -dribler2_vel);
    //delay(10);
  } 
  //Serial.print(dribler1_vel);Serial.println("   ");Serial.print(dribler2_vel);  
  // set dribblers rotation direction
  /*digitalWrite(IN1, (M1_ >= 0 ? HIGH : LOW));      
  digitalWrite(IN2, (M1_ >= 0 ? LOW : HIGH));    

  digitalWrite(IN3, (M2_ >= 0 ? HIGH : LOW));    
  digitalWrite(IN4, (M2_ >= 0 ? LOW : HIGH));    
  //update PWM pin of L298N driver
  */

}
 
void UpdateKickParameters(int time_){
  //time_ should be 0 for no kick and 35 for maximum time kick
  if(time_>maxKick)
    time_ = maxKick;
  if(time_ < 0)
    time_ = 0;
 
   digitalWrite(KICK , HIGH);
 delay(time_);
   digitalWrite(KICK , LOW);
  
}


void SetOmniControl(int Kp,int Ki,int Kd){
  omni_Kp = (Kp <= 1000 && Kp >= 0 )? Kp : omni_Kp;
  omni_Ki = (Ki <= 1000 && Ki >= 0 )? Ki : omni_Ki;
  omni_Kd = (Kd <= 1000 && Kd >= 0 )? Kd : omni_Kd;

  //Serial.print("  kp: ");Serial.print(omni_Kp);
  //Serial.print("  ki: ");Serial.print(omni_Ki);
  //Serial.print("  kd: ");Serial.println(omni_Kd);
   omni.setPid(omni_Kp ,omni_Ki ,omni_Kd);
}
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

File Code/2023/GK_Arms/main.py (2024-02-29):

from machine import Pin, UART, PWM
import utime
import _thread
import sys

led = Pin("LED", Pin.OUT)

uart = UART(0, baudrate=115200)
#uart.init(bits=8, parity=None, stop=2)

first_Time = True
defend = False

time_to_up = 500
time_to_down = 150
time_stay = 1200 - time_to_up - time_to_down

# motor_H enable forward and reverse pins
motor_en = PWM(Pin(20, Pin.OUT))
motor_fwd = Pin(21, Pin.OUT)
motor_rv = Pin(22, Pin.OUT)

# motor_H pins frequency
motor_en.freq(1000)

# motor_H pins set to low
motor_en.duty_u16(0)
motor_fwd.low()
motor_rv.low()

motor_state = "IDLE"

current_time = utime.ticks_ms()
old_time = current_time

command = "0"
        
def switch():
    global command
    global current_time
    global old_time
    global motor_state
    global motor_en
    global motor_fwd
    global motor_rv
    global first_Time
    if motor_state == "UP":
        motor_en.duty_u16(65535)
        motor_fwd.high()
        motor_rv.low()
        current_time = utime.ticks_ms()
        if current_time - old_time > time_to_up:
            old_time = current_time
            motor_state = "STAY"
            print("State STAY")
    elif motor_state == "STAY":
        motor_en.duty_u16(int((20/100)*65535))
        motor_fwd.high()
        motor_rv.low()
        current_time = utime.ticks_ms()
        if current_time - old_time > time_stay:
            old_time = current_time
            motor_state = "DOWN"
            print("State DOWN")
    elif motor_state == "DOWN":
        motor_en.duty_u16(65535)
        motor_fwd.low()
        motor_rv.high()
        current_time = utime.ticks_ms()
        if current_time - old_time > time_to_down:
            old_time = current_time
            motor_state = "WAIT"
            print("State WAIT")
    elif motor_state == "WAIT":
        motor_en.duty_u16(int((10/100)*65535))
        motor_fwd.high()
        motor_rv.low()
        current_time = utime.ticks_ms()
        if current_time - old_time > 4000:
            old_time = current_time
            motor_state = "IDLE"
            command = "0"
            print("State IDLE")
    elif motor_state == "IDLE":
        motor_en.duty_u16(0)
        motor_fwd.low()
        motor_rv.low()
        first_Time = True
        
        
def th_receive():
    global command
    while True:
        command = input()
        print("hello: ", command)


_thread.start_new_thread(th_receive, ())

while True:
    switch()
    if first_Time and command == "Defend":
        print("State UP")
        current_time = utime.ticks_ms()
        old_time = current_time
        first_Time = False
        motor_state = "UP"
        led.toggle()
        
    

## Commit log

2023-03-16 Add all CAD Files
    [BoxSupport.obj, BoxSupport2.obj, DownPlate.obj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]
2024-02-29 TDP 2024
    [BoxSupport.obj, BoxSupport2.obj, Data.xlsx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]
2025-02-26 TDP 2025
    [BellCurve.xlsx, Data.xlsx, Nova_Placa.brd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]

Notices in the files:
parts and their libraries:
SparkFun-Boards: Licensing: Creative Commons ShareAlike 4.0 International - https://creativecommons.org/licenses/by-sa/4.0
